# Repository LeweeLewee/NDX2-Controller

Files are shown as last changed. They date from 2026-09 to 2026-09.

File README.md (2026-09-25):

# NDX2-Controller

**25 September 2026: iPhone 11 + selected UGREEN Nexode 20000mAh PD 20W QC Power Bank (D030).** Physical design resumes with [concealed internal phone mounting](docs/hardware/river-stone/iphone-mount/README.md) for agreement. [Waveshare CAD/slicing is parked fallback](docs/hardware/river-stone/fallback-waveshare.md). The earlier visual implementation remains unapproved; no iOS implementation is authorized by this mounting brief. Read the [current continuation](docs/continuation-prompt.md).

A compact, battery-powered coffee-table touchscreen for native Naim music playback, starting with TIDAL.

Project repository: [leweelewee/NDX2-Controller](https://github.com/leweelewee/NDX2-Controller).

**Status: M2 hardware-independent software implemented and tested on the development host; hardware validation remains open.** See the [M2 runbook](docs/m2-software.md), [v1 contract](docs/controller-contract-v1.md) and [native firmware foundation](firmware/README.md). Native TIDAL collection browsing, album/playlist playback, queue edits, transport control and 24-bit playback have been demonstrated on an NDX 2 using a computer. Public TIDAL catalogue search and pagination also pass live tests. Search-result handoff to native Naim playback has passed through the UI; wired System Automation volume down/up are now audibly confirmed and available in the UI. The ESP32 fixture firmware and shared desktop LVGL UI now compile; the physical controller remains unbuilt and unvalidated.

The project's TIDAL developer app is created. Its metadata-only adapter retrieves ranked artists, tracks, albums and playlists. The prototype also supports voice input and live AI music discovery; microphone transcription is user-confirmed. TIDAL account collection controls and persistent Back navigation are implemented; see the collection documentation for live evidence and remaining feature coverage.

The frozen reference is tagged `software-feasibility-v1`. Start the next phase from the [milestone closeout and detailed-design handover](docs/milestone-handover.md).

**Published checkpoint and continuation, 22 September 2026:** [M2 closeout](docs/m2-closeout.md) and [continuation prompt](docs/continuation-prompt.md). The [desktop UI is approved](docs/ui-review/approval.md); the [shared LVGL port and fixture evidence](docs/m2-ui-parity.md) now cover the approved core screens and interactions. Approval does not imply native UI parity or physical acceptance.

## The product

- Compact form with flexible proportions, bespoke touch interface and a substantial, well-finished 3D-printed enclosure.
- Selected hardware: iPhone 11 and UGREEN Nexode 20000mAh PD 20W QC Power Bank (D030). Concealed mounting and exact bank variant/fit are being resolved; physical validation is outstanding.
- Large rechargeable battery and deliberate weight; cable-free use on the coffee table.
- Weeks of standby is a target, not a measured specification.
- Full TIDAL browsing and native playback; other sources can follow.

**The NDX 2 must use its native Naim TIDAL playback path.** The controller and any supporting Pi handle commands and metadata, never audio relay or transcoding. Alternative playback protocols do not satisfy this requirement.

## Documentation

Start current work with the [detailed-design plan](docs/detailed-design-plan.md), [display selection history](docs/hardware/display-comparison.md), [deployment design](docs/deployment-design.md) and [physical interaction trials](docs/interaction-design.md).

| Document | Purpose |
| --- | --- |
| [Updated design concept](docs/design-concept.md) | Historical Waveshare concept; current hardware is D030 |
| [Voice and AI discovery](docs/voice-discovery.md) | Describe a mood, refine suggestions and explore native TIDAL content |
| [TIDAL collection](docs/tidal-library.md) | Real hearts, library saves, account connection and Back navigation |
| [Prototype UI](docs/prototype-ui.md) | Run the 800 × 480 demo and configure the experimental live bridge |
| [Product brief](docs/product-brief.md) | Requirements, constraints and unresolved choices |
| [River Stone enclosure](docs/hardware/river-stone/README.md) | Stationary original 01 concept, dimensioned packaging and build constraints |
| [Hardware and parts BOM](docs/hardware/README.md) | Design baseline, parts, sourcing and validation |
| [Architecture](docs/architecture.md) | Control path, responsibilities and integration boundaries |
| [Evidence](docs/evidence.md) | What the live tests actually established |
| [Decisions](docs/decisions.md) | Agreed decisions and their rationale |
| [Roadmap](docs/roadmap.md) | Work and acceptance criteria for the next prototype |
| [Portable desktop package](docs/m2-package.md) | Bundled runtime, launcher and external-state upgrades |
| [Host controller setup](docs/m2-setup.md) | Private pairing, status, read-only verification and local recovery |
| [Development](docs/development.md) | Running diagnostics, tests and keeping records |
| [Research record](docs/research/native-tidal-feasibility.md) | Detailed research and references |

## Tools

Python 3.9+; no third-party dependencies. From the repository root:

```sh
python -m unittest discover -s tests -v
python tools/naim_native_probe.py NDX_IP --output local/naim-inventory.json
```

Replace `NDX_IP` with the streamer's private IPv4 address. The probe is read-only and saves a filtered interface inventory. It does not prove native playback by itself. See [development notes](docs/development.md) before using it.

Live reports and device-specific configuration belong in ignored `local/`. No credentials or raw network captures belong in Git. `tools/naim_client.py` is an experimental native control client; `tools/check_transition.py` is an explicit live playback test. Neither is production firmware. See the development notes for authorized live use.

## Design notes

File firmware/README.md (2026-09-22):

# Native embedded UI foundation and HP-01 build

Target: Waveshare ESP32-S3-Touch-LCD-4.3B, standard without case, SKU 27848, landscape 800 × 480. This is C/LVGL firmware, not a browser. Shared controller, protocol and UI code serve both ESP32 and SDL. Hardware operations are explicit callbacks; unsupported battery/sleep/capture report unknown or unavailable. Default startup and all verification use silent fixtures.

## Reviewed official example and pins

Reviewed 21 September 2026: [Waveshare 4.3B ESP-IDF guide](https://docs.waveshare.com/ESP32-S3-Touch-LCD-4.3B/ESP-IDF) and the [linked official archive](https://files.waveshare.com/wiki/ESP32-S3-Touch-LCD-4.3B/ESP32-S3-Touch-LCD-4.3B-BOX-Demo.zip). The guide describes SDK 5.5.2 and a differently named example; the archive contains `ESP-IDF/08_lvgl_Porting` with SDK **5.2.0** in `sdkconfig.defaults`. The inspected archive compiles with official ESP-IDF tag **v5.2**, commit `11eaf41b37267ad7709c0899c284e3683d2f0b5e`, and its GCC 13.2.0 toolchain. This establishes compilation compatibility, not board compatibility.

Archive SHA-256: `57186c266f5ed5d9cd22b80b3d3d1d19d54dec2449d7ec220c8b3abc60ee0092`.

Archive component pins: LVGL **8.4.0** (`4495f428630cc1741bd8bfd977f080e8460e8e8d`); esp_lcd_touch **1.1.2** (`54e9ba5f17d0f007f5a4073240b5f6c20e099f91`); GT911 **1.1.1~1** (`30d2504a679c1cb0d10833f772d97453098b4c08`). These component directories are already in the archive. The preparation script removes floating main component requirements and retains those vendored sources and licenses. No vendor code is committed to this repository.

Review findings: 800 × 480 selected; 16-bit RGB; PSRAM and 16 MB flash defaults; I2C 8/9 in the driver; touch disabled in the delivered header; touch reset/IRQ both `-1`; backlight delegated to vendor board code. Driver files stay in the generated project, separate from `shared/`. No GPIO4 wake assumption is implemented. The archive's BOX name is not evidence that every board revision is identical. Verify against the physical standard board before enabling touch or flashing.

## Reproducible preparation and build

From repository root in PowerShell:

```powershell
New-Item -ItemType Directory -Force local/m2
Invoke-WebRequest 'https://files.waveshare.com/wiki/ESP32-S3-Touch-LCD-4.3B/ESP32-S3-Touch-LCD-4.3B-BOX-Demo.zip' -OutFile local/m2/vendor.zip
python tools/prepare_m2_firmware.py --out local/m2/esp32-compile-v2
```

The script refuses an existing output directory or changed archive hash. For another build choose a new directory; it never overwrites a checkout. It overlays the shared C UI and ESP entry point, disables stock auto music/demo UI, and inserts wake-contact filtering before LVGL input. Touch remains off until revision review. After that review, prepare a **new** output directory with `--touch-reviewed`. This flag does not configure any wake GPIO or sleep mode.

Install official ESP-IDF **v5.2** and matching tools outside the repository. On this Windows host the SDK lives at `$env:USERPROFILE/.espressif/esp-idf-v5.2`, with its isolated Python 3.11 environment at `.espressif/python_env/idf5.2_py3.11_env`. Installation for a new host (use a base Python 3.11 interpreter, not an activated virtual environment):

```powershell
git clone --branch v5.2 --depth 1 --recurse-submodules --shallow-submodules https://github.com/espressif/esp-idf.git "$env:USERPROFILE/.espressif/esp-idf-v5.2"
py -3.11 "$env:USERPROFILE/.espressif/esp-idf-v5.2/tools/idf_tools.py" install --targets esp32s3
py -3.11 "$env:USERPROFILE/.espressif/esp-idf-v5.2/tools/idf_tools.py" install-python-env
python tools/build_m2.py esp32
```

The runner refreshes only owned overlay sources in the generated directory, validates its archive marker, and disables unused vendor demos. Build output uses `$env:USERPROFILE/.espressif/ndx2-m2-build` to avoid Windows dependency-file path limits; source remains in this checkout. The fixture binary compiled successfully (approximately 516 KiB, fitting its 1 MiB application partition). No flash or efuse operation ran. Save configuration/build manifests privately. HP-01 remains open; flashing requires the actual board and revision review.

## Shared SDL desktop build

The verified Windows runner pins CMake 3.28.3, Ninja 1.11.1.1, Zig 0.13.0 and SDL 2.30.12. From repository root, after preparation and SDK installation:

The downloaded SDL development archive SHA-256 is `dddafbf0705a8cbe1f97c69680886ce147ed4d38f1d04e03523681298e081b0f`. Verify a fresh download before extraction. These instructions reproduce the dependency versions and build process; generated binary timestamps and local paths can affect binary hashes.

```powershell
python -m pip install --target local/m2/build-tools cmake==3.28.3 ninja==1.11.1.1 ziglang==0.13.0
Invoke-WebRequest 'https://github.com/libsdl-org/SDL/releases/download/release-2.30.12/SDL2-devel-2.30.12-mingw.tar.gz' -OutFile local/m2/SDL2-devel.tar.gz
tar -xzf local/m2/SDL2-devel.tar.gz -C local/m2
python tools/build_m2.py desktop
python tools/m2_native_demo.py
```

Both native CTests pass. Run `local/m2/desktop-verified/ndx_fixture.exe` for the standalone fixture. `m2_native_demo.py` uses that compiled UI, SDL pointer events, synthetic pairing and real localhost TLS; it asserts one silent native-play request and refreshed state, then records thirteen framebuffer BMPs in ignored `local/m2/native-captures`. The SDL transport worker launches `m2_pipe.py`; credentials remain in the protected Python vault and never cross the pipe. A public config supplies `url`, `trust` and `state` paths; live connections require an explicit `allow_live` setting. Tests never enable it. This Windows transport is not a portable desktop release. See [M2 runbook](../docs/m2-software.md).

## Diagnostic and physical boundaries

ESP32 emits `HP01` timestamped fixture event names plus free/minimum heap. Hooks include boot, native-resolution simulation, bounded amplifier simulation, capture cancel, backlight-unbound and sleep-blocked. Add revision-specific timing/PSRAM/power markers as the board port becomes available; no token, address or user query is logged. Record serial/debug overhead and repeat power measurements detached. Physical HP-01 still needs backlight-off and verified light/deep-sleep implementations; unsupported callbacks deliberately fail rather than pretending to measure sleep.

`esp32/bridge_transport.c` implements the same v1 codec using `esp_http_client` on a FreeRTOS worker, with provisioned CA trust, hostname verification, redirect rejection, bounded 32 KiB responses, deadlines and no mutation retry. Replies from obsolete connection generations are discarded. Startup requires encrypted NVS plus runtime secure boot and flash encryption; default builds fail closed to the labelled fixture. Protected NVS namespace `controller` expects `url` (ending `/v1/request`), `credential`, `trust` (PEM), `ntp`, `ssid` and `password`. This is a provisioning interface, not a completed production provisioning tool. Do not enable irreversible security settings or provision real credentials from this recipe. The SDK compiles the worker, but default fixture builds may link out its gated network path. On-device Wi-Fi/TLS, certificate-time bootstrap, revocation, protected provisioning and power-loss behaviour remain untested. Provider credentials remain on the bridge. See [hardware-arrival checklist](../docs/m2-software.md#hardware-arrival-checklist).

## Approved native UI port — 22 September 2026

The shared renderer now implements the D020 core layout and interaction slices; see [parity/evidence](../docs/m2-ui-parity.md). Native smoke includes immediate-record voice entry, restart, explicit search, cancel, an accelerated 30-second stop without submission, independent artist-follow/track-save and consumed wake contact. `06-voice-search.bmp` supersedes the historical review-step capture; thirteen captures now document the flow. Font sizes 16/20/24/32 are explicitly enabled by the owned build overlay, retaining LVGL 8.4.0 and ESP-IDF v5.2. No new SDK/dependency download or board operation is needed.

## Authenticated artwork preview - 22 September 2026

Shared LVGL/codec accept fixed 80 x 80 RGB565 artwork previews over the authenticated bridge. No firmware image-decoder dependency or SDK pin changed. Three CTests cover controller state, strict protocol bounds and native UI cancellation/artwork failures. Desktop TLS smoke checks artwork pixels before/after a silent track change. Latest ESP32 build: `0x92c00`, 43% free; compiler evidence only. Standalone firmware fixtures have no artwork pixels yet.

The host bridge uses already-installed Pillow 12.2.0 for bounded JPEG normalization and local fixtures. Host dependencies are pinned in `tools/requirements-m2.txt` (also cryptography 46.0.7 for certificates). On a fresh host install that file with the chosen Python environment; no download was needed for this checkpoint. See [bounds and evidence](../docs/m2-artwork.md).

## Persistent local preferences - 22 September 2026

Palette/brightness intent/timeout use the shared bounded preference record and local platform storage callbacks. Windows uses SDL's per-user `NDX2/Controller` directory, or `--preferences PATH` with an existing parent. The ESP32 NVS adapter uses `display_prefs/record`, never erases on storage error and does not change credential protection gates. No hardware brightness/sleep effect is implemented.

Run `python tools/m2_preferences_demo.py` after the desktop build for isolated two-process restart evidence and native captures. All smoke tools supply temporary preference paths, preserving normal user preferences. Four CTests now include atomic storage/recovery and native save behavior. ESP32 storage remains compiled-only; physical latency/power-loss/endurance are open. See [preferences runbook](../docs/m2-preferences.md).

## Offline recovery checkpoint

After the desktop build, run `python tools/m2_recovery_demo.py` to exercise the real worker/helper over paired TLS with startup outage, delayed replies and a new bridge boot ID. All commands target silent fixtures. Four CTests include expanded LVGL recovery assertions; the separate transport executable is driven by this Python fixture rather than standalone CTest. Shared UI uses an eight-second pending deadline, generation invalidation and conservative unknown outcomes. ESP32 compiles (`0x971f0`, 41% free); no physical networking or recovery is claimed. See [recovery evidence](../docs/m2-recovery.md).

## Host enrollment foundation

New desktop controller records can be created with the tested host enrollment library and are bound to their supplied HTTPS origin/trust file. The helper validates these bindings; legacy fixture records remain compatible. `python tools/m2_provisioning_demo.py` exercises enrollment/revocation/replacement using temporary synthetic state and verified loopback TLS. This does not create ESP32 NVS images, expose secrets or enable the gated hardware transport. See [design, recovery and evidence](../docs/m2-provisioning.md).

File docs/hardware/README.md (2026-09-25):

# Hardware

> **D030 update — 25 September 2026:** active hardware is iPhone 11 + selected UGREEN Nexode 20000mAh PD 20W QC Power Bank. See [current mounting and power packaging](river-stone/iphone-mount/README.md). Waveshare-specific parts, experiments and purchase recommendations below are fallback history; actual prior order records remain valid. This update does not cancel orders or authorize more purchases.

Status: concept and parts planning; no physical build or purchases recorded.
Last reviewed: 21 September 2026.

**Selected, 21 September 2026 (D017): Waveshare ESP32-S3-Touch-LCD-4.3B, standard without case (SKU 27848), 800 × 480.** Android is ruled out. Hardware validation remains outstanding; no purchase is recorded.

Start with the [Waveshare HP-01 protocol](first-experiment.md) and [next-phase plan](../detailed-design-plan.md). The [Android comparison](display-comparison.md) is retained as superseded history, not active work.

Current enclosure: **original 01 River Stone, stationary on the table**. See [dimensioned packaging and construction study](river-stone/README.md).

Repurposed phones are excluded from the current design for visual reasons; a dismantled-phone approach is not being pursued. Use a dedicated display assembly; see [decision D015](../decisions.md#d015--dedicated-display-repurposed-phone-route-ruled-out).

## Design baseline

- Compact coffee-table controller with a bespoke touch UI and a substantial, serviceable 3D-printed enclosure.
- Rectangular or square proportions are acceptable: screen quality and interaction take priority over aspect ratio.
- A separate large rechargeable battery lives low in the base. An included small battery adds no selection value.
- Weeks of standby is a target, not a measured specification. Screen-off standby is the working LCD direction; keeping now-playing continuously visible has a different energy budget.
- Touch wake remains a requirement to validate. Powering down the entire display board also disables its touch electronics unless a wake circuit remains powered.
- Native Naim TIDAL playback stays on the NDX 2. Controller and optional existing Pi carry commands and metadata only.

## Documents

| Document | Purpose |
| --- | --- |
| [Hardware design](design.md) | Electrical boundaries, physical layout and screen record |
| [Parts BOM](bom.md) | Authoritative part IDs, quantities, status, sourcing and costs |
| [Research and selection](research.md) | Open decisions, candidate routes and next actions |
| [Power component review](power-review.md) | Source findings, shortlist and compatibility gates |
| [Power budget and validation](validation.md) | Runtime assumptions and hardware acceptance checks |

## BOM management

Use one stable HW identifier per functional item. The BOM is the source of truth; do not maintain a second independently edited spreadsheet.

Selection states: **existing**, **selected**, **preferred**, **candidate**, **research**, **design**, **optional**, **excluded**.
Track procurement separately: **not ordered**, **ordered**, **received**, **assembled**, or **existing / inventory unverified**. A preferred part is not a purchase instruction.

Before ordering, record exact manufacturer part number, board revision, supplier link, quantity, connector/polarity requirements, dated unit price and currency. Record shipping and taxes separately. Unknown cost is **TBD**, never zero. Included functions are not additional purchased parts. Alternatives are mutually exclusive, not additive.

After receiving a part, record actual revision and dimensions, paid cost, sanitized order reference and validation evidence. Keep private receipts/account details in ignored local/. Record substitutions and accepted choices in [decisions](../decisions.md), hardware results in [evidence](../evidence.md), and milestone changes in [roadmap](../roadmap.md).

Complete the software control-loop milestone before final component purchase and final enclosure CAD. Research and provisional layout work can proceed now.

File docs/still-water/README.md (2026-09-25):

# Still Water: visual design package for the native UI

> **Current selection — 25 September 2026 (D030):** user selected iPhone 11 and UGREEN Nexode 20000mAh PD 20W QC Power Bank. Waveshare is parked fallback. Earlier “selection open” text below is historical. [Concealed mounting proposal](../hardware/river-stone/iphone-mount/README.md) governs the current physical discussion; the 118 × 54 mm window remains provisional. The draft custom battery/boost/MCU architecture, operating configuration and runtime expectations below are not validated or adopted wholesale. Do not execute embedded implementation prompts from this hardware-selection update.

23 September 2026. Design handover for the Still Water UI, platform-neutral pending screen selection between the iPhone 11 (`iphone-architecture.md`) and the Waveshare 4.3B (`spec.md` Appendix A). Bridge protocol semantics, recovery, security and D011 are out of scope and must not change.

| File | Purpose |
|---|---|
| `iphone-architecture.md` | Roles, phone configuration, display window, app modules, power module, budget and the measurement gates |
| `spec.md` | The design: principles, tokens, rest-state machine, every screen in design units with coordinates, artwork colour extraction, fonts, motion, abnormal states, acceptance criteria |
| `decision-draft.md` | D028 wording for the decision log |
| `codex-prompt.md` | Two briefs: bridge additions now (platform-independent), and the iOS app once the screen is selected |
| `evaluation.md` | The design evaluated against the project goals and the automated gate, with what was changed as a result |
| `reference/still-water.html` | Interactive prototype, 22 states (open in a browser; fictional music, no device commands) |
| `reference/*.png` | Reference renders of all 22 states at exactly 800 × 480 design units, at the spec type sizes |
| `tools/still-water-gates.py` | Playwright script that renders every state and checks targets, overlaps, text size, contrast and clipping |

## This sprint

Lock the design, not the platform: extend the prototype to the full state matrix, freeze this spec at v1.0, put the prototype on the iPhone 11 on the table under Guided Access, run the two-day standby measurement, and have Codex do only the bridge additions. Choose the screen at the end of the sprint; then one final build.

## Scope

In: visual composition, typography, colour, hierarchy, motion, touch layout, rest ladder timing based on last touch and transport state.

Out: presence sensing, light seam, enclosure CAD changes beyond the inlay window, queue editing, AI suggestions beyond the existing search path, any new network route from the phone, always-on operation, any battery claim.

## Panel check

Section 0 of `spec.md` records the iPhone 11 panel facts and section 0b the window and unit mapping; Appendix A records the Waveshare panel facts and LVGL implementation notes.

## Precedence

D027 authorises this redesign of the visual layer and D028 (draft) the platform. Where this package conflicts with `docs/m2-object-design.md` pixel geometry or `docs/hardware/design.md` display selection, this package wins. Where it conflicts with `docs/decisions.md`, `docs/controller-contract-v1.md` or `docs/m2-recovery.md`, those win and the conflict should be recorded in the roadmap rather than resolved silently.

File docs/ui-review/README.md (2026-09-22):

# Approved UI design

The user approved the desktop design on **22 September 2026**, after the icon-only Search refinement. [Approval and baseline identity](approval.md) governs the design; [index.html](index.html) is its interactive visual reference. [Historical notes](review-history.md) preserve earlier proposals without making them current requirements.

## Review locally

From the repository root:

```powershell
python tools/ui_design_review.py
```

Open http://127.0.0.1:8766/. This loopback-only server exposes the board and an optional existing fixture capture, with no player, bridge API, credentials or microphone access. Missing `local/m2/native-captures/01-now.bmp` affects only the comparison image. Browser-local notes/preferences are not repository acceptance evidence.

## Current baseline

- 800 × 480; 240 px artwork left, metadata and all controls right. Four sections: Playing, Find, Collection, Queue. Voice is inside Find.
- Five evenly spaced, unboxed controls: previous, play/pause, next, speaker-minus, speaker-plus. Quiet Back; no redundant section titles, Volume label, play circle or volume capsule.
- Bitrate beside source, separate timeline; track heart and title/artist/album links. Real metadata must be authoritative or explicitly unavailable.
- Artist follow/unfollow and status; album/track + Library or checked Library; saved, unsaved and unknown remain distinct.
- Magnifying-glass search and microphone icons. Microphone opens recording immediately; Stop & search, Restart, Cancel. Thirty-second bound, no automatic submission or playback.
- Settings via gear: Display, Connection, Device; Sage/Sand/Slate, brightness and timeout preferences, Wi-Fi/pairing/setup and diagnostics direction.

Settings, membership, bitrate and recording are labelled simulations. Brightness is a browser visual approximation; timeout is stored without implementing sleep. Alternative artwork/navigation options are comparison aids, not additional required modes.

## Implementation boundary

The browser board is approved design, **not ESP32 runtime or proof of shared LVGL parity**. Port it to the existing shared C/LVGL UI, retain authenticated bridge semantics, and validate desktop flows before hardware. Loading/error/transcription-failure details may need further design review. Touch sizes, wake release, readability, battery and microphone still require physical evidence. HP-01 and physical P3/P4/P5 remain open.

Continue with [the implementation handover](../continuation-prompt.md). No queue/playlist editing or automatic AI playback is included.

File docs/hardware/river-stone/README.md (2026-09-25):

# Original 01 River Stone: stationary enclosure

> **Visual reference confirmed: original 01 River Stone only**, for both body and screen interface. Concealed iPhone mounting must preserve microphone acoustic paths.

> **25 September 2026: active hardware is iPhone 11 + selected UGREEN Nexode 20000mAh PD 20W QC Power Bank.** Start with the [concealed mounting layout, section and paper aperture trial](iphone-mount/README.md). Everything below describing the Waveshare packaging, CAD and slicing is [parked fallback history](fallback-waveshare.md); its dimensions and print next steps do not govern the iPhone build.

Status: dimensioned packaging study, 20 September 2026. Original visual concept selected by the user; stays on the coffee table. Dimensions and construction details below are engineering proposals, not user-approved measurements or manufacturing release.

**Latest manufacturing check:** [P1S slicing study and small fit-trial 3MF](slice-v1/README.md). Provisional Generic PLA; physical testing pending.

**Latest CAD revision:** [v3 reinforced shell, matching cover and screen-edge bevel](shell-v3/README.md). Full-shell print release remains pending.

**Shell baseline, 21 September 2026:** see the [shell and assembly study](shell-v1/README.md) for actual solids, revised component positions and insertion clearance. The plan-view study below is retained as its starting point.

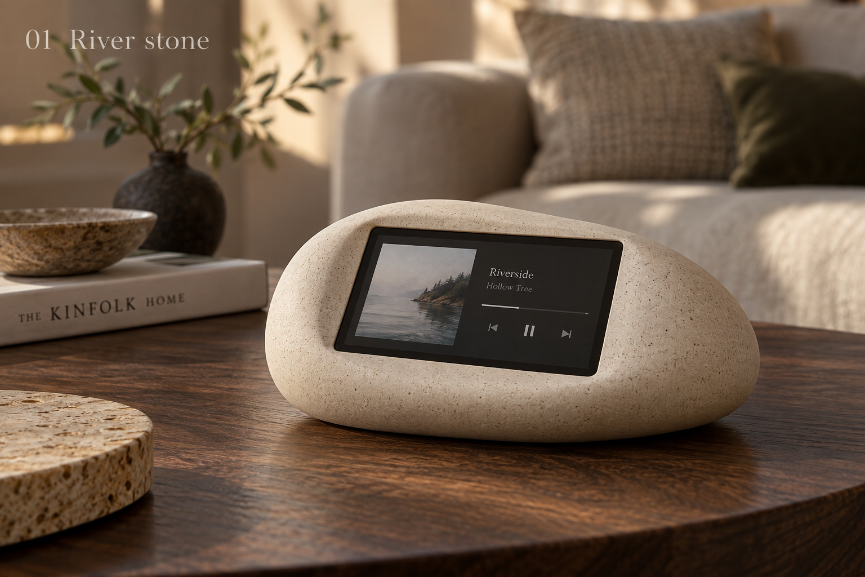
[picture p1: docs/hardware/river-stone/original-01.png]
Selected original River Stone


Preserve the original's low asymmetric pebble, soft shoulders, inset landscape screen and mineral surface. The four later variations and Crescent embrace are superseded. Do not evolve this into an exposed monitor stand or stacked removable controller.

## Architecture and simplicity

One stationary controller, one battery, one main shell and one recessed underside cover. No separate handheld battery, angle rails, docking magnets, transmitter/receiver or controller-to-base charge transfer. Rear cable charging is the working proposal; ordinary operation remains cable-free. This does not select a charger or wiring scheme. Existing external charger/power-path research remains applicable.

The P1S and 0.4 mm nozzle are the user's home manufacturing constraint. Prefer a filament surface that is acceptable directly from the printer. Fine stone-effect speckling is a visual direction, not a selected filament. Material compatibility, nozzle requirements and sample finish must be checked for the exact product; no assumption that all mineral-filled filaments suit the stock nozzle. Acetone smoothing and painting are not requirements.

## Dimensioned layout

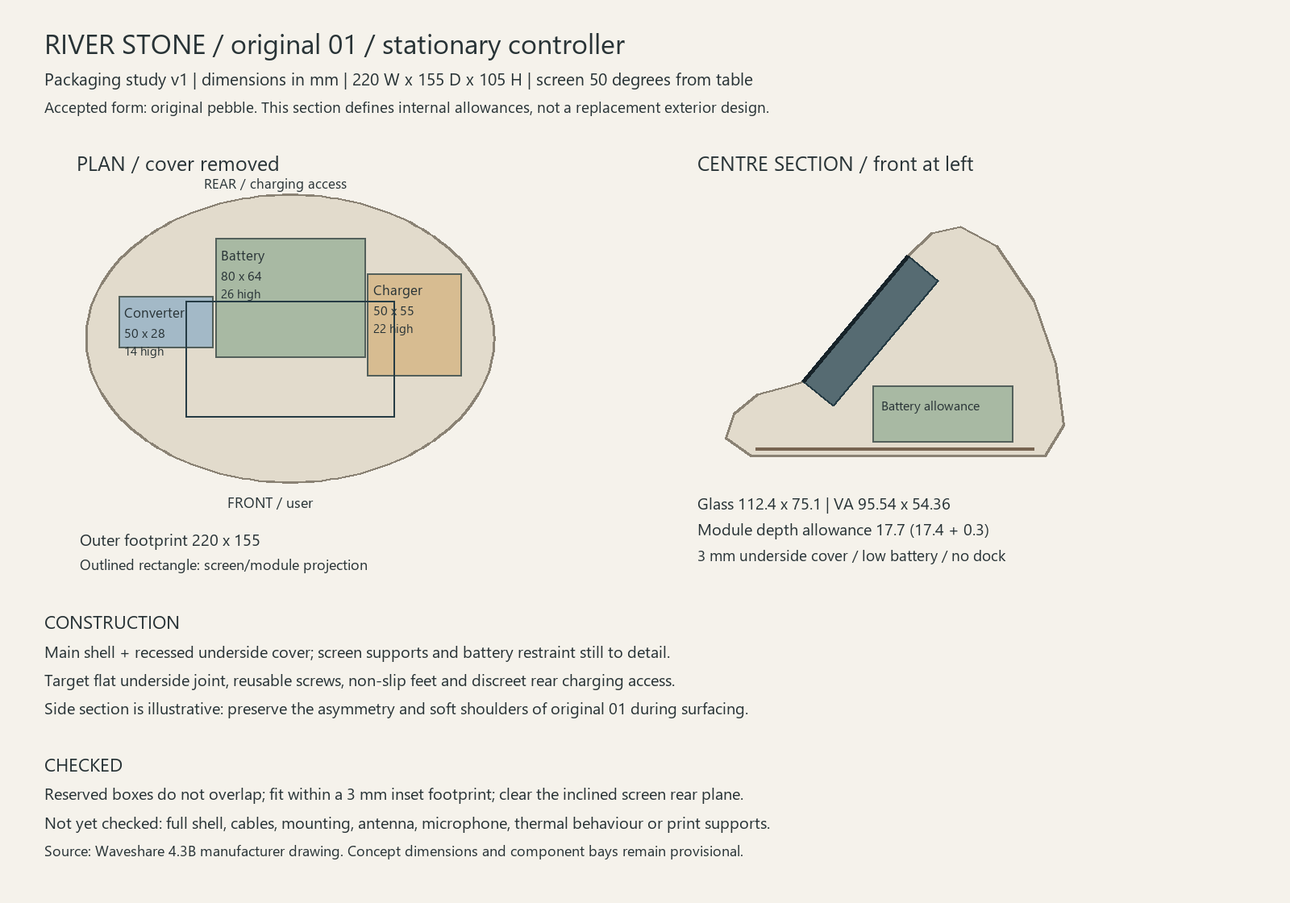
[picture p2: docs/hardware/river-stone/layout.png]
Packaging plan and side section


[Vector drawing](layout.svg) · [Numerical checks](clearance-checks.json) · [Generator](../../../tools/river_stone_layout.py)

| Item | Working allowance |
|---|---|
| Overall body | 220 W x 155 D x 105 H mm; bounding envelope, not an optimized minimum |
| Screen | 50 degrees from table, lower lens edge 34 mm above underside datum |
| Lens | 112.4 x 75.1 mm; supplier tolerance +/-0.1 mm each |
| Visible area | 95.54 x 54.36 mm; supplier tolerance +/-0.15 mm each |
| Screen module depth | 17.7 mm allowance includes drawing's 17.4 +/-0.3 mm; excludes plugged cables |
| Battery space | 80 x 64 x 26 mm, starting 6 mm above underside |
| Charger space | 50 x 55 x 22 mm, rotated planning allowance |
| Converter space | 50 x 28 x 14 mm |
| Shell / cover | Start with 3 mm nominal; final shell offset, ribs, joints and inserts unresolved |

Coordinates in the generator: X left/right, Y positive rear, Z positive up; underside datum Z=0. Bay sizes are installation reservations, not supplier dimensions. Battery reference is the earlier 69 x 54 x 18 mm protected pack candidate; it is not purchased or electrically approved. A rectangular reservation must not be mistaken for an actual serviceable cavity.

The screen's 800 x 480 pixel canvas is not its physical aspect ratio. Use the manufacturer's VA dimensions for physical visualizations. Source: [Waveshare drawing archive](https://files.waveshare.com/wiki/ESP32-S3-Touch-LCD-4.3B/ESP32-S3-Touch-LCD-4in3B_Drawing.zip). The drawing was downloaded and visually inspected; the local original source is retained with the design-session artifacts. No mounting-hole or cable-clearance release is inferred from these measurements.

## What the checks establish

The three rectangular reservations are mutually disjoint, fit inside an ellipse with each semi-axis reduced by 3 mm, and lie below the infinite rear plane of the inclined screen module. This ellipse is a footprint approximation, **not a true constant-thickness offset of a final shell**. Normal gaps to the screen rear plane are battery 8.10 mm, charger 3.01 mm and converter 19.64 mm. The charger gap is the tightest: mounts, cable routes and tolerances may require moving it or increasing the envelope.

The side section is an illustrative centre profile. It is not the exterior CAD surface; the original image governs the asymmetric shoulders. Full shell clearance, fasteners, cable plugs/bends, antenna clearance, microphone hardware, touch force stability and heat are unverified. Do not print this drawing as a fabrication template or buy components based on it.

## Assembly proposal

1. Print the main shell and removable underside separately. Start evaluating the shell with its underside opening toward the bed; flatten the hidden joint rather than supporting a rounded underside. Screen aperture edges and upper internal surfaces still need a slicer overhang check. A no-support claim is premature.
2. Insert the screen from below through the open underside. Use discrete internal mounting supports and a compliant perimeter gasket; no concentrated fastener load on the glass. Retainer geometry and insertion sweep follow actual board mounting details.
3. Fit an insulated removable battery restraint and the two power boards to the underside assembly. Allow a service loop so the cover can open without pulling connectors. Do not compress the pack. Keep antenna clearance and optional microphone placement out of the battery/ballast region.
4. Close using reusable screws into designed bosses/inserts. An initial four-screw concept is reasonable, but coordinates and lengths must follow the interior layout. Put non-slip feet where they do not conceal required service screws.
5. Provide a discreet rear inlet and strain relief appropriate to the eventual power path. Preserve programming access. A slot or port cut-out is not released until the chosen connector, plug and cable bend are modelled.

## Next engineering work, without another concept-selection gate

- Build the asymmetric shell surface to the original reference, using these reservations as keep-outs. Assess whether the 105 mm high rear can be lowered while retaining the screen angle and access.
- Incorporate the manufacturer's STEP and measured connector/mount information; perform a real shell offset and insertion-path check before a fit STL.
- Resolve charger placement with its actual board outline and wiring; maintain the existing power research limits. Battery current and runtime require bench evidence.
- Reserve microphone hardware consistent with the accepted voice feature; do not silently omit it or claim its volume is already proven.
- Slice a partial bezel/mount sample before committing to the full decorative shell, then test viewing and touch on the actual table.

The only later user input likely to matter is actual seated usability or a choice between credible finish samples. This study does not require another aesthetic confirmation.

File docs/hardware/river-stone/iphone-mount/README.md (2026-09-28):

# iPhone 11 / stone mounting proposal

25 September 2026. **Active hardware: iPhone 11 and the user-selected UGREEN Nexode 20000mAh PD 20W QC Power Bank (D030).** The Waveshare enclosure and slices are [parked fallback work](../fallback-waveshare.md). This document proposes the mechanical interface for agreement; it records the accepted paper aperture but does not release fit CAD or authorize an app implementation.

## Reference and intended appearance

Sole visual reference: original 01 River Stone

**User clarification, 25 September 2026: original 01 River Stone is the sole visual reference for both the body and screen-to-stone interface.** Preserve its low asymmetric pebble, soft shoulders, inset landscape screen and mineral finish while adapting the internals for iPhone 11 and the selected UGREEN bank. The supplied “04 Tide pool” image is retained only as superseded reference history; do not use its bowl/rim geometry to drive the design. The section diagram below explains mounting layers only and does not prescribe the exterior contour.

## Mounting layout — revised 27 September 2026

Front, section, underside and acoustic reservations

[Layout checks](layout-checks.json) · [1:1 paper aperture template](mask-trial.svg) · [Reproducible layout generator](../../../../tools/iphone_mount_layout.py)

The user repeated the selected bank name, UGREEN Nexode 20000mAh PD 20W QC Power Bank, and authorized proceeding. Use the matching manufacturer's 147 × 72 × 28 mm envelope to progress the layout; the exact physical unit and port arrangement still require checking before a fitted cradle. This is a working assumption, not a substitution of another power bank or a request to reopen the selection.

| Proposal | Working value |
|---|---|
| Overall planning bounds | 240 W × 170 D × 105 H mm |
| Phone angle | 50 degrees from the table |
| Lower phone glass edge | 36 mm above underside datum |
| Visible aperture | 138.9 × 63.7 mm bounds; size passed by user; 6 mm inset from every outer phone edge |
| Aperture corner radius | R3 mm all four corners; user passed the rounded aperture trial |
| Local glass recess | 1.2 mm trial target |
| Bank bay | 151 × 76 × 32 mm, around the 147 × 72 × 28 envelope |
| Rear-of-phone reserve | 6 mm beyond nominal phone body, not a measured camera dimension |
| Phone connector / bank service reservations | 25 mm each at opposite sides; actual plugs and bend radius unmeasured |

The bank sits across the base, low and behind the inclined phone. Coordinates and exact reservations are in the JSON. The bank bay clears the conservative infinite phone-rear allowance plane by **15.08 mm vertically** at its closest corner. This is only an analytical plane/box check. It does not establish curved-shell clearance, fitting tolerances, vent dimensions, screw access, insertion or temperature. Body dimensions and tilt are engineering proposals; they are not dimensions recovered from the original concept image. Revisit them after the mask and hardware measurements.

Use a cradle with open front-notch, rear-camera and connector-end zones. Avoid a full clamshell around the phone. Keep long-edge buttons free; place padded chassis supports only after mapping the actual button and microphone positions. Interrupt the light-seal gasket around the front acoustic inlet and preserve an open route beneath an optically concealing lip. Reserve a separate rear-camera acoustic route and keep the Lightning-end openings clear of cable plugs and restraints. Vents must open to room air above the table contact plane, not into a sealed bank cavity. The sketch shows protected zones, not verified inlet coordinates or finished ducts. Exact port mapping and mounted recordings are mandatory before claiming unobstructed microphone performance.

Assembly proposal: phone into cradle, cradle into open stone, connect lead, then fit the separately restrained bank and underside cover. The projected volumes overlap, so assume the bank must come out first for phone removal; independent phone removal with the bank installed is not proven. No load-bearing back clamp over the phone battery, and no lens contact.

Print the paper template at 100% and verify its 50 mm scale. Cut the window and hold the mask over the phone without sticking it across the earpiece or any microphone opening. Check notch/edge concealment, oblique views and touch reach; remove the paper for unmounted voice baselines. The next 3D sample should reproduce the aperture edge and interrupted gasket/acoustic passage, not just a decorative frame. Compare Voice Memos and front/rear camera recordings, then the intended voice app, at the same distance/orientation before and after mounting. Apple provides separate microphone checks for [voice recordings and both camera directions](https://support.apple.com/en-gb/101600). This is a test plan; nothing has been physically recorded or printed here.

## Recommended construction

Interface schematic

Mount the intact, case-free phone from inside/underneath the stone in a removable cradle. Keep the phone's battery and housing intact. Locate it on padded chassis/perimeter supports with clearance for buttons and the rear camera bump; do not load the camera lenses, active display or battery area. Rear keeper screws close against cradle hard stops, rather than squeezing the phone tighter as they turn. The cradle attaches to internal bosses and can be removed after opening the underside cover.

An opaque stone lip conceals the phone perimeter; notch and corner concealment must be checked with the enlarged opening. A thin, replaceable black closed-cell gasket under that lip controls light leaks and the visible joint; it is not the structural clamp. Keep pad contact on verified non-display perimeter regions. The exposed touch surface is the phone's own glass: no added glass/acrylic overlay, external phone frame or adhesive bonding to the phone. A separate hidden mask insert remains available if printing the stone lip cleanly proves difficult; it is not an extra required visible trim.

Use a shallow local glass recess, initially around 1–1.5 mm for a physical mock-up, with a gently relieved stone edge. That is a proposal, not a print tolerance. The surrounding pebble surface follows original 01 River Stone; the immediate aperture edge must allow a fingertip to reach controls. Avoid a deep vertical tunnel. Keep interface controls away from the lip and verify at seated viewing angles; app layout must match the physical aperture rather than squeezing the entire iPhone interface into view.

## Window and phone envelope

Apple specifies the iPhone 11 body as **150.9 × 75.7 × 8.3 mm**, 194 g, with a 1792 × 828 LCD. These are nominal product dimensions, not a mounting drawing: measure the actual phone, camera projection, buttons and cable plug before fit CAD. [Apple specifications](https://support.apple.com/en-gb/111865).

**26 September revision:** the user rejected the 118 × 54 mm opening as too small and subsequently reduced the proposed overlap to **6 mm measured inward from the outer phone edge**. Apply this to all four edges as the next trial baseline: (150.9 − 12) × (75.7 − 12) = **138.9 × 63.7 mm**, centred on the phone body. This is approximately **38.9% more rectangular opening area**, not a claim about active pixel area. The width and height subsequently passed the user’s physical trial; R3 corner geometry also passed on 27 September; any local microphone relief remains to be verified.

Maximise display exposure within this baseline. A uniform overlap does not prove that the notch is hidden or that the front microphone is clear. Check registration on the actual phone; use local lip relief and an interrupted gasket wherever needed to leave the inlet and a short, broad path to room air open. Do not shrink the whole aperture again merely to hide the notch. Exact relief dimensions await microphone mapping; the rounded paper template is a visual registration aid only. The earlier 755 × 346 pt/1048 × 480 design-unit mapping is superseded for this aperture and must be recalculated from actual screen registration before UI work.

Propose notch left and Lightning connector right when viewed from the front. The notch is at a short end in landscape; the home indicator is along the bottom long edge, not the opposite short end. A physically masked display cannot rely on normal edge gestures for everyday controls. Preserve underside service access for unlocking, exiting the app, restarting and reconnecting; hiding sensors may prevent Face ID and alter automatic brightness. These operating choices need a real phone trial, not assumptions from the concept image.

## Selected power bank and service access

Use the selected UGREEN bank intact in a separately retained bay, low in the base, with access to its button/indicator and charging ports. Do not transfer the earlier bare-cell charger/boost board stack into this architecture automatically. Do not stack the phone directly onto the bank; reserve separation and heat escape paths, and measure charging temperature in the closed enclosure.

The user's product name is the selection. SKU 25683 is a possible match, **not a confirmed substitution**. UGREEN's 25683 listing gives 147 × 72 × 28 mm and 435 g ±5 g; use those only as conditional planning data until the exact SKU is confirmed. Plug bodies, strain relief and cable bends are additional. [UGREEN manufacturer listing](https://www.ugreen.com/en-au/products/au-25683). Earlier 80 × 64 × 26 mm battery reservations cannot accommodate that conditional envelope, so the Waveshare base layout is not reusable as an iPhone fit claim.

A concealed USB-to-Lightning lead is the simplest first charging proposal. Reserve room beyond the phone's connector end and route without trapping the cable beneath the phone. Phone and bank should be removable independently. **Firm user constraint: mounting must not obstruct the iPhone microphones.** Map the actual microphone openings before fixing the cradle, gasket or masking lip; preserve their acoustic paths, including around the connector end. Provide concealed acoustic openings where the stone would otherwise enclose them. Revise the masking rather than sacrifice microphone access. Validate voice pickup in the assembled enclosure; no acoustic performance is claimed yet.

Bank automatic shutoff/restart, concurrent charging/output, charge-window switching, low-load behaviour and total runtime remain unproven. The bridge's D029 charge advice is software evidence only: it does not make this commercial power bank remotely switchable. The older draft MCU/load-switch/pack-gauge architecture and runtime estimates are not adopted by selecting this bank.

## Accepted paper aperture — 27 September 2026

The user passed the window size and subsequently passed the R3 corner revision. The accepted aperture baseline is **138.9 × 63.7 mm, 6 mm overlap from each outer phone edge, and R3 mm circular corners on all four corners**. Preserve these dimensions in subsequent mounting CAD. The radius is in the opening plane; it does not specify a bevel or fillet through the lip thickness. This records the user's paper-template fit result, not independent measurement of the iPhone screen radius.

Next develop the small aperture-and-cradle sample around this accepted opening. Recess, edge touch access, retention, exact microphone passages and mounted acoustic performance remain unverified. Preserve open microphone paths and interrupted gasket.

## Agreement and next physical proof

Recommended agreement: **rear-loaded intact phone; serviceable padded cradle; opaque stone lip; hidden black light seal; original phone glass exposed; shallow local recess.** The user suggested rear/inside mounting; the aperture dimensions above are accepted; cradle and recess dimensions remain proposals.

Before detailed CAD: verify the UGREEN variant; register a removable 138.9 × 63.7 mm paper/card mask with 6 mm overlap on each edge over the actual phone; display alignment marks at the intended UI corners; check notch/edge concealment from sofa and oblique angles, touch at the lip, wake/unlock and voice. Then measure the phone/plug/camera/bank and make a small aperture-and-cradle sample. No need to print the old Waveshare coupons to advance this architecture. Keep printer constraints (P1S, 0.4 mm nozzle, minimal finishing) and the luxury living-room appearance as design gates.

## First printable interface sample — 27 September 2026

[Sample v1: STL, STEP, preview and trial instructions](sample-v1/README.md) preserves the passed aperture and adds an open frame plus loose recess gauges. This is a hand-supported fit sample, not a retaining cradle. CAD and mesh checks passed; slicing, printing and acoustic validation remain outstanding.

## Revised fit sample — 28 September 2026

Use [sample v2](sample-v2/README.md) for the next print. It adds four short end-locating tabs with nominal 1 mm end clearance and 36 mm central end openings, preserving the accepted aperture and existing rails/spacers. No clamping or snap fit. CAD body-clearance and exported mesh checks passed; actual microphone, camera, button and insertion checks remain physical work. V1 is preserved.

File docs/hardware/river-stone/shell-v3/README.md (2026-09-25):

# River Stone reinforced-shell study v3

> **PARKED FALLBACK — 25 September 2026 (D030).** This is Waveshare-specific work, preserved without changing its geometry/results. Active design is [iPhone 11 mounting](../iphone-mount/README.md); old printing/next-step instructions below are suspended. See [fallback status](../fallback-waveshare.md).

21 September 2026. Dedicated Waveshare 4.3B without case, stationary original 01 River Stone. **CAD study, not a complete print or powered-build release.**

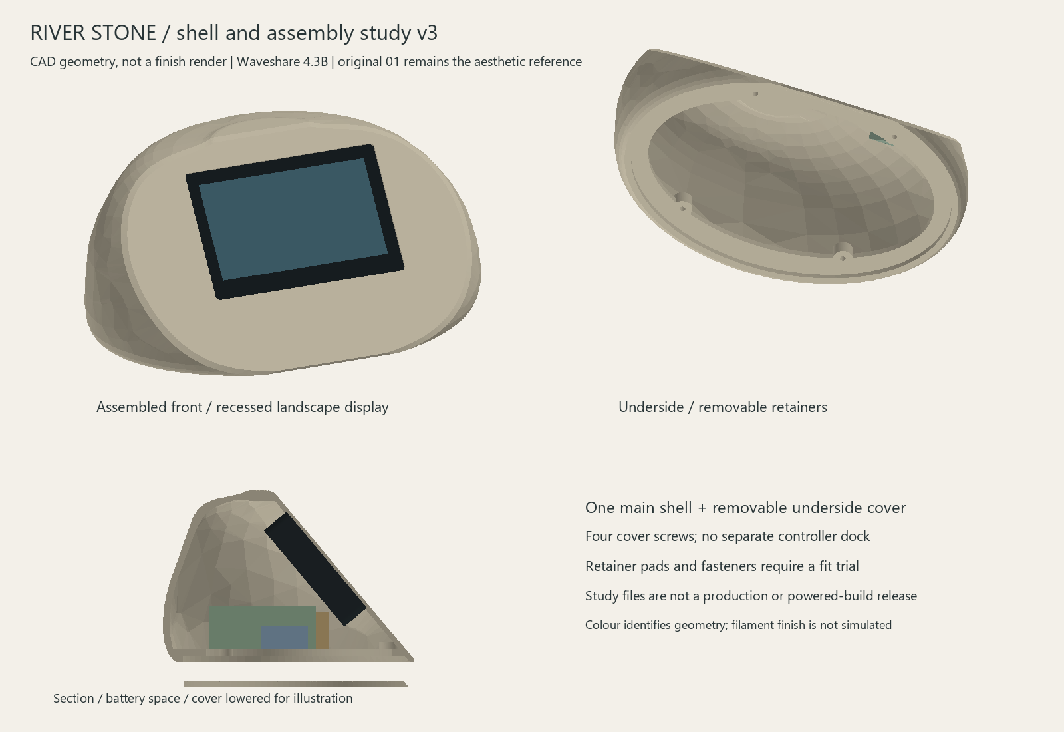
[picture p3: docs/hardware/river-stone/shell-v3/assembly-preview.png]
Revised shell


The lower rim is reinforced internally over its first 3.5 mm. Cover screw bosses now extend down to the ledge base at Z=3.5 mm, strengthening the junction beside their holes. The two upper cavity rings are lowered by 3 mm and its closing cap by 2 mm to add material beneath the crown. A 2 mm bevel now breaks the perimeter of the screen facet. This is a narrow chamfer, not the broad soft blend attempted in v2; further aesthetic refinement may still be needed against the original reference.

The shell remains approximately 220.1 x 151.1 x 103 mm. The matching underside cover is now 199.4 x 135.4 x 3 mm, reduced to clear the reinforced rim. Use the v3 cover with the v3 shell. The four cover fasteners, 50-degree display angle, side retainers and battery/power reservations retain their previous positions. The added shell material increases enclosed solid volume from about 206.3 to 229.8 cm3; this is not a slicer filament-volume estimate.

## Files

- [Shell STEP](shell-study.step) and [STL](shell-study.stl).
- [Matching cover STEP](cover-study.step) and [STL](cover-study.stl).
- [Assembly STEP](assembly-envelopes.step): includes retainers and conservative display/power envelopes.
- [Geometry validation](validation.json), [mesh validation](mesh-validation.json) and [print audit](print-audit.json).
- [Mount coupon](retainer-mount-coupon.stl) and [retainer coupon](retainer-strip-coupon.stl): unchanged from v2. See [fit-trial procedure and retention limitations](../shell-v2/README.md).

Seven exported meshes pass watertightness, consistent winding, positive volume, single-component and 256 mm cube checks. The fixed bosses and reinforced shell still clear the continuous conservative display-insertion path with retainers removed. Seated display, cover, glass/PCB proxies and component reservations pass the applicable collision checks. Actual cables, connector details and glass contact/load are not proven.

## Print audit

A seeded audit of 10,000 area-weighted face-centre rays found an exit for every ray. Minimum sampled depth is approximately **1.000 mm**, at the intentional screen lip. No samples are below 1 mm using a 0.0001 mm numerical tolerance. The first percentile is 2.065 mm, fifth percentile 3.000 mm and median 3.912 mm. This removes the sub-1 mm findings from the delivered audit; it does not prove that every possible section exceeds that value.

An intermediate v3 check located a 0.746 mm junction beside a rear cover screw hole. Extending the cover bosses through the ledge resolved that sampled issue. The final report contains the hash of the checked STL, matching the mesh-validation report.

Downward surface area beyond the 45-degree criterion is approximately **13,795 mm2 underside-down** and **5,328 mm2 screen-facet-down**, excluding bed-contact triangles. Reinforcement has not made the shell support-free.

The audit samples inward normal rays from mesh face centres. It cannot certify the global minimum wall thickness or print strength. Overhang areas classify triangle normals; they are not support-volume or slicer predictions. The visible face would touch the bed in the facet-down orientation, so lower overhang area alone does not establish the best print orientation. The preview uses coarse flat triangle shading; that appearance is not the intended filament texture.

Full-shell slicing, retention fit against the actual board, gasket loading, battery restraint, connectors, microphone/antenna space and electrical integration remain open. First inspect and slice the small fit coupons on the P1S with the intended filament and 0.4 mm nozzle. No slicing or physical testing was performed in this revision.

## Regeneration

Dependencies: CadQuery 2.8.0; numpy/Pillow for rendering; trimesh with scipy/networkx for checks. The CAD, mesh and audit commands accept `--deps PATH` for a local dependency directory.

```text
python tools/river_stone_shell.py --revision v3
python tools/render_river_stone.py --revision v3
python tools/check_river_stone_meshes.py --revision v3
python tools/audit_river_stone_print.py --revision v3 --samples 10000
```

The generator preserves explicit v1/v2 options; v3 is the new default. Earlier revision artifacts remain unchanged except for documentation that makes regeneration versions explicit.

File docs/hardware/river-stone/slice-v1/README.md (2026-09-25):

# River Stone P1S slicing study and fit trial

> **PARKED FALLBACK — 25 September 2026 (D030).** This is Waveshare-specific work, preserved without changing its geometry/results. Active design is [iPhone 11 mounting](../iphone-mount/README.md); old printing/next-step instructions below are suspended. See [fallback status](../fallback-waveshare.md).

21 September 2026. Based on [shell v3](../shell-v3/README.md), dedicated Waveshare 4.3B and stationary original River Stone. Offline slicing completed; no printer connection, print, or physical fit test occurred.

## Small fit trial

Open [fit-coupons.3mf](fit-coupons.3mf) in OrcaSlicer to review the two sample parts and their generated toolpaths. [Combined STL](fit-coupons.stl) is also included for your preferred slicer. The source samples are unchanged v3 geometry, arranged with broad flat faces down. The combined STL contains two disconnected parts intentionally.

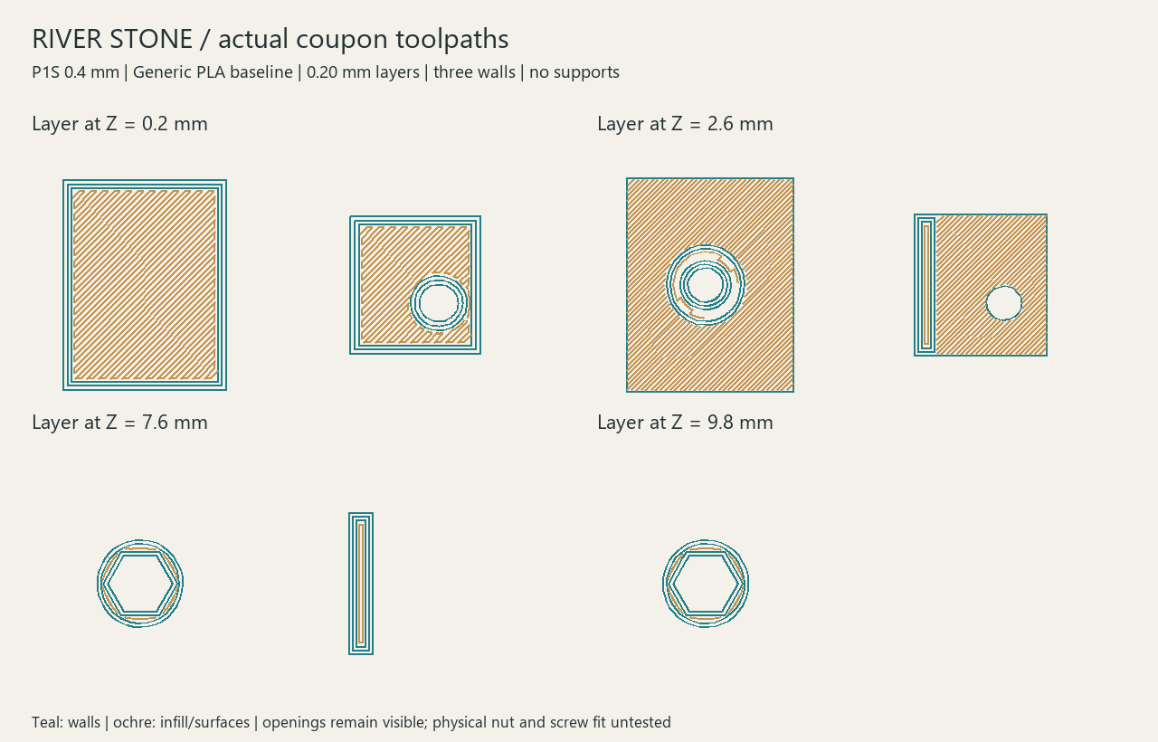
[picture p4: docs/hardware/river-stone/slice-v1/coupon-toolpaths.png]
Actual toolpath samples


The 3MF uses **P1S, 0.4 mm nozzle, Generic PLA, textured PEI, 0.20 mm layers, three walls and 15% infill, no supports or brim**. The inherited profile sets a 220 C nozzle and 55 C bed. Generic PLA and the plate are provisional assumptions for this study; check the actual spool and installed plate before printing or re-slicing. This is not a selected enclosure material or finish.

Slicer estimate: **15 minutes 49 seconds total, 2.73 g PLA**, 50 layers. Startup contributes approximately 6 minutes 16 seconds to that estimate. The coupon plate is within the P1S bed; exported metadata reports no outside-bed placement and no support use. Selected actual toolpaths were inspected at Z=0.2, 2.6, 7.6 and 9.8 mm. The screw passage and upper hex nut pocket remain open where intended. The mount coupon's bed-facing panel is intentionally blind, like its enclosure attachment face. Toolpath viewing does not establish dimensional fit.

All three slices retain Orca's `bed_temperature_too_high_than_filament` warning (1000C001, level 3). It occurred with the inherited Generic PLA/55 C textured-plate profile. This is recorded rather than hidden or described as a warning-free pass. Review the warning in the slicer against your actual filament and enclosure setup before printing. No temperature adjustment was validated physically.

After the small print, check that the intended nut seats without splitting the boss, the screw passes through the retainer coupon freely, and the pair can be tightened and removed by hand without stripping or bottoming. Record actual hardware dimensions, filament, plate, layer height and measured hole/nut fit. Keep glass out of this trial; the pads and actual Waveshare contact still require validation. A successful coupon does not release the full shell.

## Shell orientation comparison

Both orientations slice successfully with the same provisional PLA/P1S profiles and normal automatic supports permitted on the model as well as the bed. The shell profile keeps the no-brim baseline. These are baseline estimates, not optimized support settings or a final print orientation.

| Orientation | Estimated total time | Slicer filament estimate | Commanded support volume |
|---|---:|---:|---:|
| Underside down | 7h 43m 59s | 289.08 g | 74.44 cm3 |
| Screen facet down | 6h 18m 02s | 224.85 g | 21.84 cm3 |

Facet-down reduces the estimate by about 1h 26m and 64 g, but the visible front face contacts textured PEI and the bevel/shoulders still need support review. Underside-down keeps that broad visible face off the bed but uses much more support, including support in the hollow body. Removal access and marks remain physical questions. The two orientations therefore stay open until a surface sample establishes which leaves an acceptable result with little finishing.

Support volume is calculated from positive extrusion commands on XY/arc moves tagged as support or support interface, using the declared 1.75 mm filament diameter. It excludes Custom startup/purge moves and is not measured consumption. Total filament and time are Orca estimates. Independent support layers account for layer counts that can exceed height divided by 0.20 mm. Successful slicing does not prove support removability, print stability, strength, glass loading or finish quality.

The prepared orientation STLs and result summaries are retained here. Full-shell sliced projects/G-code remain in ignored local work folders; the full housing remains **not released for printing**.

## Reproducibility and sources

- [OrcaSlicer 2.4.2 official release](https://github.com/OrcaSlicer/OrcaSlicer/releases/tag/v2.4.2), Windows x64 portable archive; its checksum is in [source.json](source.json).
- [Official CLI documentation](https://github.com/OrcaSlicer/OrcaSlicer/wiki/cli_mode).
- Flattened profiles derive from Orca's bundled BBL profiles: `Bambu Lab P1S 0.4 nozzle`, its compatible `0.20mm Standard @BBL X1C`, and `Generic PLA`. Inheritance is resolved before the documented overrides. The profile names identify their base; the process settings are modified as listed above. The bundled [AGPLv3 license](profiles-LICENSE.txt) is retained for this third-party material. The slicer binary is not committed.
- [Coupon result](fit-coupons-result.json), [underside-down result](shell-underside-down-result.json), [facet-down result](shell-facet-down-result.json), [toolpath and warning review](toolpath-review.json). Hashes tie each result to its geometry, profiles and local G-code.

Run from repository root with Python, trimesh/numpy and Pillow installed:

```text
python tools/prepare_river_stone_slice.py --slicer-zip PATH_TO_OFFICIAL_PORTABLE_ZIP
python tools/slice_river_stone.py --slicer PATH_TO_ORCA_EXE --job fit-coupons
python tools/slice_river_stone.py --slicer PATH_TO_ORCA_EXE --job shell-underside-down
python tools/slice_river_stone.py --slicer PATH_TO_ORCA_EXE --job shell-facet-down
python tools/review_river_stone_toolpaths.py
```

Preparation accepts `--deps PATH` for the local trimesh installation. Slicing runs without a visible window and writes no commands to a printer. G-code timestamps mean a regenerated checksum may differ even when the settings and geometry match.

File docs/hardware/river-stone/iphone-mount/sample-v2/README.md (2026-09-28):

# iPhone aperture fit sample v2

28 September 2026. Open, hand-supported sample for the accepted **138.9 × 63.7 mm / R3 aperture with 6 mm overlap**. Original 01 River Stone remains the exterior reference; this test fixture does not define the stone silhouette.

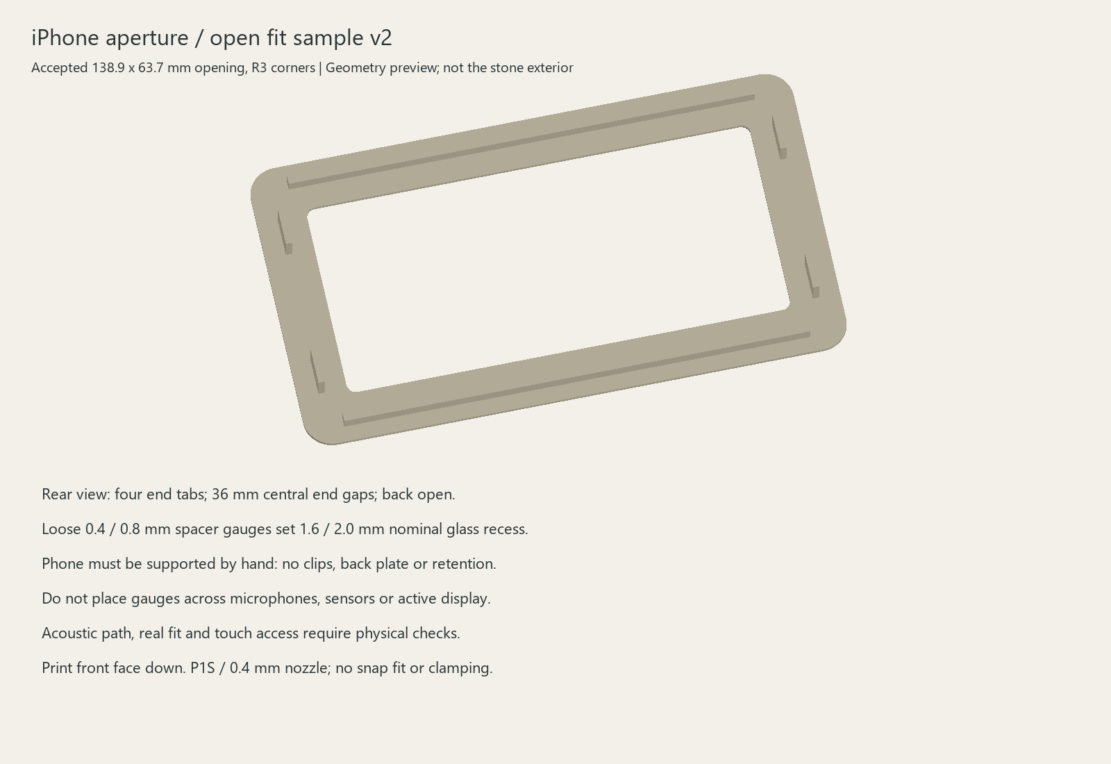
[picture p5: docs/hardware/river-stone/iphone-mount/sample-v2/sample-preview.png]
CAD rear view


## Files and printing

- [Frame STL](aperture-frame.stl) / [STEP](aperture-frame.step).
- [0.4 mm spacer gauge](spacer-0.4mm.stl) and [0.8 mm spacer gauge](spacer-0.8mm.stl). Duplicate four of the chosen thickness in the slicer. Do not mix thicknesses.
- [Solid checks](validation.json) / [STL checks](mesh-validation.json).

P1S with 0.4 mm nozzle. Trial starting point: familiar plain PLA, 0.2 mm layers, three walls, front face flat on the bed as exported. Use the normal profile for the actual filament and plate. Inspect sliced layers and spacer adhesion. No slice, time estimate or G-code is validated here.

Frame: 170 × 95 × 9.2 mm. Lip: 1.2 mm. Four end-locating tabs added; back remains open. Two long-edge stiffeners have a 79 mm inner gap versus nominal 75.7 mm phone width. The existing long rails remain unchanged. End tabs are 2 mm thick × 12 mm long × 8 mm high above the lip, with inner faces 152.9 mm apart: 1 mm nominal clearance at each end of the 150.9 mm body. Two tabs per end leave a 36 mm central opening above the lip. These are deliberately loose locators, with no snap-fit, overhang or back clamp. Exact button, microphone and camera clearance is not verified. Geometry is designed to grow from the flat flange without unsupported overhangs.

## Trial

1. Inspect for burrs, flatness and dimensional error before bringing the print near glass. Do not force the phone between rails.
2. Support the phone by hand from behind: **there is no retention**. Keep the rear camera, microphones, connector and buttons clear; do not rest the rear camera on a worktop.
3. Centre the accepted paper mask to register the opening. Select four spacer positions on the actual non-display perimeter, away from microphones, sensors and buttons. Positions are deliberately not fixed in CAD. Do not place gauges on active pixels. If safe positions cannot be established, hold the frame clear and report that before adding retention.
4. Compare 0.4 mm spacers (1.6 mm nominal glass recess including the lip) and 0.8 mm spacers (2.0 mm recess). Added protective film or padding increases the gap. Final recess remains unselected.
5. Check corner concealment, alignment, edge touch access and seated/oblique views. Keep cable plugs clear of microphone openings.
6. Check straight rear insertion/removal and record side-to-side movement. The nominal free movement is 2 mm along the phone length and 3.3 mm along its width; keep the phone centred for aperture assessment. Confirm each tab clears the real hardware, not just the nominal body. The central gaps reserve access but are not measured microphone keep-outs.
7. Compare bare-phone and sample-mounted voice recordings at the same orientation and distance using the intended app and existing Voice Memos/front/rear camera checks. Do not add continuous gasket or tape across inlets. An open back or narrow gap alone does not prove an unobstructed acoustic path.

Production retention, screw stops, padded supports and acoustic passages follow actual hardware mapping. This sample tests aperture/lip access and rear-loading space; it is not a finished cradle and does not validate the eventual closed stone's acoustics.

## Verification

Three valid CAD solids; zero intersection between accepted aperture cutter and frame. The nominal body box at the shallowest spacer setting does not intersect the frame. Both 36 mm central end channels are clear above the lip. These checks exclude protruding buttons/camera, cable plug and acoustic performance. All three STL meshes are watertight, consistently wound, single-component and fit within 256 mm. Preview comes from actual CAD tessellation. No physical printing or voice test claimed.

Reproduce with tools/iphone_mount_sample.py --deps followed by the CadQuery dependency directory; tools/check_iphone_mount_sample.py --deps followed by the trimesh directory; and tools/render_iphone_mount_sample.py. Python 3.12 with CadQuery 2.8, NumPy/Pillow and trimesh was used. Pass --revision v2 to all three tools (the current default); --revision v1 reproduces the earlier sample.

## Revision scope

User authorized short locating tabs at both ends to obtain more fit data in one print. Aperture, corner radius, flange, long rails and spacers are unchanged. The original [v1 sample](../sample-v1/README.md) is preserved. Use v2 for the next print; the two spacer meshes are identical to v1 and need not be reprinted if already available. This fixture still requires hand support and does not lock the phone in place.

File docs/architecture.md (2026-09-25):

# Architecture

> **D030 update — 25 September 2026:** iPhone 11 + selected UGREEN power bank replace Waveshare as active physical hardware. [Mounting/interface proposal](hardware/river-stone/iphone-mount/README.md) is under discussion. Earlier Waveshare hardware/UI implementation details below are retained fallback; native playback and bridge security requirements remain. This physical-design update does not implement or approve the entire iPhone software/power draft.

## Detailed-design status — 21 September 2026

D017 selects Waveshare ESP32-S3-Touch-LCD-4.3B without case and rules out Android. D018 specifies a provisional embedded-controller/always-on-bridge partition; Pi reuse depends on private host inventory. See [deployment design](deployment-design.md) for credentials, pairing, renewal and recovery gates, and [phase plan](detailed-design-plan.md) for dependencies. The development-host v1 bridge, secure storage/recovery, desktop contract harness and native LVGL fixture foundation are implemented; see [M2 software](m2-software.md) and [contract](controller-contract-v1.md). The ESP32 HTTPS worker is implemented and compiled; protected provisioning, on-device networking, Pi hosting and physical validation remain open. The optional/direct paths below describe feasibility-era architecture, not the current deployment recommendation.

## Required playback path

```mermaid
flowchart LR
    UI[Native 800 x 480 controller] -->|Authenticated HTTPS| PI[Always-on bridge: development host; Pi conditional]
    PI -->|Native commands and metadata| NDX[Naim NDX 2]
    TIDAL[TIDAL service] -->|Native Naim audio retrieval| NDX
    NDX --> AMP[Existing Naim amplifier]
```

This is the intended architecture. The solid local control path was exercised from a computer; the native firmware fixture compiles and the shared LVGL UI passes a desktop TLS fixture flow, and Pi deployment remains conditional. Network packets to TIDAL were not independently captured, but the live native endpoint, native queue class and player source identified the Naim TIDAL path. The test process fetched no audio.

## Responsibilities

**Controller:** rendering, touch input, local UI state, cached artwork, sleep/wake policy and battery monitoring. It sends high-level requests and rechecks actual device state after reconnecting.

**NDX 2:** native music retrieval and decoding, native queue and playback state. Existing amplifier integration must be preserved.

**Bridge (provisional D018):** provider credentials, search/collection adapters, artwork processing, voice/AI and native Naim commands. Development-host implementation exists; the Pi is a conditional hosting option after inventory. Home Assistant's web page is reachable; no authenticated HA integration has been inspected or installed.

## Observed local interface

The tested NDX 2 exposes HTTP port 15081, API 1.4.0 and appVer 3.11.0.5662. Firmware changes could affect behaviour.

| Operation | Observed request or reference |
| --- | --- |
| System information | `GET /system` |
| Input descriptions | `GET /inputs` |
| Current playback | `GET /nowplaying` |
| Native queue | `GET /inputs/playqueue` |
| Favourites | `GET /favourites` |
| Native content | Returned `inputs/tidal/artists/...`, `albums/...`, `playlists/...`, `tracks/...` references |
| Single native track playback | `GET /inputs/tidal/tracks/{returned-id}?cmd=play` |
| Stop request | `GET /nowplaying?cmd=stop` |

Some GET requests mutate playback. HTTP method alone is not a read-only guarantee. The diagnostic tool uses a fixed command-free allowlist.

Native playback reports `source=inputs/playqueue`, `sourceDetail=tidal`; the queue item class was `object.track.tidal`. Merely seeing playqueue is not enough to identify the music source.

Do not assume every duration uses the same units: the track description returned seconds, while now-playing duration and advancing position appeared in milliseconds. Negative position occurred during startup. Production parsing needs explicit per-field handling and tests.

## Extensibility

Separate UI requests from service adapters and Naim player commands. Future providers must satisfy the same native-playback requirement. Avoid building a universal audio server as a shortcut. Native queue edits and wired System Automation amplifier control have passed live tests. Search uses the project’s public TIDAL catalogue adapter. Native search syntax is not required by this prototype; long-running authentication renewal and recovery remain deployment validation work.

## Catalogue metadata prototype

The computer-side UI uses a loopback-only Python bridge in tools/prototype_ui.py. It runs a labelled demo by default; optional live catalogue and NDX configuration use the existing adapters. This is an implementation aid for the chosen display, not a committed Pi deployment or ESP32 firmware architecture. See [prototype scope and validation](prototype-ui.md).

tools/tidal_catalog.py implements public TIDAL catalogue search separately from native Naim playback. It uses this project's own developer credentials, sends only metadata requests, and returns candidate native IDs for subsequent resolution on the NDX. It does not import Naim credentials, fetch playback manifests or transfer audio. Credentials and tokens stay in the computer/Pi process; provider secrets will not be deployed to the controller (D018). Live search and pagination pass for artists, tracks, albums and playlists. Public search → native track resolution → playback has passed through the UI. AI discovery supplies catalogue queries only; see [voice discovery](voice-discovery.md).

## Account collection and phase boundary

The prototype also uses the project’s own TIDAL OAuth authorization for collection read/write, with exact album/artist metadata links and native resolution before playback. See [collection integration](tidal-library.md). The computer bridge is a proven reference implementation, not a selected final deployment. Software feasibility is closed; [the handover](milestone-handover.md) governs detailed design and records the remaining reliability and hardware gates.

## Approved UI implementation boundary — 22 September 2026

D020 approves the [desktop design](ui-review/approval.md). Its core screens and interactions are now ported to the shared C/LVGL renderer and bounded state model. The browser board remains a design artifact, not ESP32 runtime. [Native parity and evidence](m2-ui-parity.md) records the metadata/collection/voice extensions, current desktop tests and firmware compilation, and remaining artwork/device integration. Native adapter semantics and the separate physical acceptance gates are unchanged.

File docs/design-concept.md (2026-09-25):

# Coffee-table controller — design concept

> **D030 update — 25 September 2026:** iPhone 11 + selected UGREEN power bank replace Waveshare as active physical hardware. [Mounting/interface proposal](hardware/river-stone/iphone-mount/README.md) is under discussion. Earlier Waveshare hardware/UI implementation details below are retained fallback; native playback and bridge security requirements remain. This physical-design update does not implement or approve the entire iPhone software/power draft.

Revision 0.2 — 20 September 2026. Published baseline for parts investigation and the first UI prototype.

## Selected screen for the concept

**Waveshare ESP32-S3-Touch-LCD-4.3B, standard version without case (SKU 27848).** Use its 4.3-inch colour IPS touchscreen and 800 × 480 landscape canvas as the working prototype baseline. ESP32-S3, Wi-Fi and touch are integrated. This is the user's preferred prototype selection; hardware validation and final purchase selection remain open.

This replaces the earlier approximately square e-paper screen assumption. The physical direction is now the original 01 River Stone, stationary on the coffee table; see D014. The enclosure follows the actual display assembly, rather than forcing square proportions.

See the [manufacturer's display documentation](https://docs.waveshare.com/ESP32-S3-Touch-LCD-4.3B) and the maintained [hardware design](hardware/design.md) for specifications and mechanical references. The [parts BOM](hardware/bom.md) is the authoritative component list; this concept does not duplicate prices or connector specifications.

## Physical character

The original 01 River Stone: a low asymmetric pebble with inset landscape display and a refined mineral surface. It stays on the table; there is no separate handheld controller. The [dimensioned packaging study](hardware/river-stone/README.md) proposes a 220 x 155 x 105 mm envelope and 50-degree screen angle, both provisional. A substantial rechargeable battery sits low in the base, contributing stability and weight. The base is non-slip, the glass has perimeter protection, and a removable underside gives access to the battery and electronics. Final dimensions, fasteners, wall thickness and charging access follow component measurements.

Cable-free coffee-table use remains mandatory. A discreet rear cable charging inlet is the working proposal; controller-to-base charging is outside the stationary design. Weeks of standby remains an unmeasured target. With the selected LCD, standby means the screen turns off. Touch wake and whole-board consumption must be demonstrated; an always-visible now-playing screen has a separate energy budget.

## First UI prototype

- **Now playing:** prominent album artwork, track and artist, source, transport and queue access.
- **Find music:** touch-sized search field, artists/albums/tracks/playlists filters and ranked result rows; selecting an item opens a detail view before play or queue actions.
- **Collection:** native Naim favourites and their children, preserving the streamer's returned references.
- **Queue:** current queue inspection and clear feedback for additions. Do not display a requested change as a confirmed playback result.
- **Wake and reconnect:** retrieve fresh player state. When disconnected, show that state and leave browsing available where possible.

Use 800 × 480 as the design canvas, with large controls and restrained warm accents on charcoal. A computer browser is a software prototype only: it cannot validate touch accuracy at physical size, LCD power, ESP32 frame rate or wake latency.

The first UI excludes amplifier volume until the actual System Automation command passes an audible test. The user subsequently requested voice and natural-language AI discovery, now included in the computer prototype. See [voice discovery](voice-discovery.md) for behaviour and outstanding microphone hardware work. The palette stays adjustable to the final enclosure material.

## Required software path

TIDAL catalogue metadata → resolve the chosen reference through native Naim browsing → native Naim play/queue command → verify player state. The NDX 2 retrieves and decodes the audio. The controller and optional Pi carry commands and metadata only.

Public catalogue search and pagination have passed live tests. Native collection playback, queue commands and 24-bit playback have also passed independently. Combining a public search result with native playback has now passed through the UI on the home network. Full personalized TIDAL functionality is not yet established.

## Independent investigation tracks

| Track | Inputs now available | Evidence needed before final selection |
| --- | --- | --- |
| Display and embedded UI | Exact Waveshare candidate; 800 × 480 canvas | Touch usability, rendering, wake behaviour and firmware pin availability |
| Battery and power | Large protected pack in base; existing onboard power path to assess first | Whole-board active/sleep measurements, charging rate, shutdown and runtime |
| Enclosure | Original River Stone, stationary, serviceable underside, low battery placement | Actual board/connector/pack dimensions, antenna clearance, stability and fit |
| Software | Catalogue and native clients; working live evidence | Search-to-native handoff, app coexistence, recovery and audible amplifier control |

Record parts and research in [Hardware](hardware/README.md), accepted changes in [Decisions](decisions.md), and measurements in [Evidence](evidence.md). Parts research can proceed alongside the UI; final purchases and enclosure CAD still follow the software feasibility gate.

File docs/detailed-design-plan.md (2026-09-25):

# Detailed design and hardware proof

> **D030 update — 25 September 2026:** iPhone 11 + selected UGREEN power bank replace Waveshare as active physical hardware. [Mounting/interface proposal](hardware/river-stone/iphone-mount/README.md) is under discussion. Earlier Waveshare hardware/UI implementation details below are retained fallback; native playback and bridge security requirements remain. This physical-design update does not implement or approve the entire iPhone software/power draft.

Started 20 September 2026. Updated 21 September: parallel M2 software implementation is now present; see [implementation, validation and hardware-arrival checklist](m2-software.md). No hardware or Pi deployment proof is claimed.

**Scope update, 21 September 2026:** Waveshare ESP32-S3-Touch-LCD-4.3B without case is selected; Android is ruled out (D017). The [comparison](hardware/display-comparison.md) is retained as history. HP-01 is the first hardware experiment; purchase and hardware proof remain outstanding.

## Reference and audit

The annotated tag `software-feasibility-v1` resolves to commit `aa070fc0af4a616f769a7c0f15790831c90c112c`. At the original phase-entry audit HEAD matched that commit; subsequent documentation and packaging commits extend it. Preserve the tag and computer prototype as the comparison reference; do not redesign its playback route or restart feasibility research.

Read together: [handover](milestone-handover.md), [decisions](decisions.md), [architecture](architecture.md), [hardware index](hardware/README.md), and all five documents linked by that index. The audit also inspected collection/voice documentation and the bridge/token adapters. Findings:

| Area | Established in repository | Unresolved / next deliverable |
| --- | --- | --- |
| Playback and amplifier | Computer-side native TIDAL, queue operations and bounded wired System Automation proven | Preserve adapters and D011 semantics; exercise integration/recovery, not a new audio path |
| Display | HW-001 exact preferred model recorded; manufacturer references only | Actual revision, physical usability, memory/render load, accessible pins and touch wake |
| Energy | Wh model and candidate external power route exist; no measurements | Whole-board standby and wake energy before battery sizing; no weeks-of-use promise |
| Power components | Onboard large pack on hold; external charger/boost shortlisted | Net-level revision review, low-load losses, peak/thermal limits, isolation and backfeed |
| Voice | Browser capture/transcription proven | No microphone selected; bus/pin availability, capture amid music, acoustic opening and power |
| Deployment | Loopback HTTP server, in-memory credentials and refresh logic exist | Persistent secure service, controller authentication, renewal/revocation and recovery |
| Interaction | 800 × 480 browser proof | Physical target sizes, keyboard, wake contact, busy/unknown/error behavior |
| Packaging | Base battery and serviceable printed shell required | Measured parts, cable/insertion clearances, thermals and seated touch stability |

The packaging work originally inspected as untracked is now recorded in commit `ef2576c`: `docs/hardware/river-stone/` and `tools/river_stone_layout.py`. Their README records a selected stationary River Stone concept and P1S/0.4 mm manufacturing constraint. Carry that direction into packaging review without reopening aesthetics. Its dimensions/reservations are proposals, not fit or electrical evidence. The phase plan does not release that layout for manufacture.

Two stale records described amplifier control as unresolved; the BOM and R10 now point to D011. No physical cable identification or new cable purchase is implied. The deferred browser discrepancy is B01 below; its cause is unknown.

## Work packages and gates

Sequence: P0 → P1; P2 and P3 specification can proceed during P1; P1 + P2 + P3 → P4 → P5. Procurement is separate from design approval. Time estimates depend on equipment availability; no purchase is recorded or authorized by this plan.

| Work | Deliverable | Dependencies | Acceptance / stop condition |
| --- | --- | --- | --- |
| P0 — bench readiness | HW-001 availability, equipment inventory and dated purchase proposal if needed | Existing BOM | Exact selected 4.3B without case; suitable supply/measurement equipment; purchasing approval before ordering |
| P1 — screen/touch/power proof | [Waveshare HP-01 report](hardware/first-experiment.md), reproducible firmware/build settings and sanitized traces | P0, revision-matched schematic/example review | Usable screen, repeated touch wake and measured power states; diagnose failures before integration |
| P2 — deployment proof | [Deployment design](deployment-design.md), host suitability record, service/config/recovery tests | Read-only Pi inventory; no existing HA workload changes without a concrete migration plan | Secure restart restores authorization; renewal, revocation, controller pairing and lost-command recovery pass; HA workload remains healthy |
| P3 — interaction and microphone | [Physical UI trial](interaction-design.md), task results; pin/bus budget and microphone capture report | P1 display; fixture bridge available before P2 deployment | Core tasks usable at actual size; transcript review/cancel works; recording stops on exit; microphone capture under display/Wi-Fi load succeeds |
| P4 — power selection | Measured battery-side energy budget, selected pack/charger/converter and wiring drawing; revised BOM | P1 loads, P3 microphone load, agreed use profile | Peak margins, standby budget, charge/use thermals, low battery and service isolation pass against chosen component ratings |
| P5 — fit and integrated prototype | Measured component CAD, bezel/mount sample, serviceable fit print and integration report | P1 dimensions, P3 acoustics, P4 selected parts | No glass point loads/pack compression; insertion and service paths work; charging, RF, heat and touch stability pass in housing |

P2 starts with a thin controller UI plus an always-on metadata/control bridge as the working architecture. Use embedded UI firmware on the selected Waveshare; Android work is retired. Reusing the existing home-automation Pi is preferred conditionally, not an assertion that its OS supports the service. See deployment gates before installing anything. A separate host is a fallback only if resource/isolation constraints require it; no new host purchase now.

## Parallel software preparation

While hardware is unavailable, the next software task can implement a development-host bridge, fixture-backed controller contract, recovery/security tests and an embedded UI/build foundation using the selected Waveshare assumption. This extends parallel preparation beyond specification; it does not pass P1, physical P3 or Pi deployment acceptance. Keep hardware-specific interfaces replaceable and distinguish simulation, compilation and live observations. Implementation started after repository cleanup: protected bridge state, authenticated TLS fixtures, navigation/recovery and native UI/build sources are now available. The shared desktop LVGL TLS flow, two native C tests and ESP32 fixture compilation now pass; provisioning and on-device network validation remain open. P2 software tests proceed independently of P0/P1; host suitability and physical gates remain open.

## First practical action and evidence discipline

Execute HP-01 on the selected Waveshare using USB power before connecting a large battery. It tests touch wake, standby consumption and recovery. Confirm board and instrument availability first; until hardware is available, complete revision-matched schematic review and prepare the build recipe. A desktop demo is not hardware proof.

Store private captures, host inventory, addresses, receipts and recordings under ignored `local/`. Commit sanitized summaries with date, board revision, firmware commit/build configuration, instruments, measurement boundaries, durations, failures and raw-evidence location. Add conclusions to [evidence](evidence.md) only after observation; update decisions and roadmap at each gate. A failed gate is useful evidence, not grounds to silently change native playback or touch-wake requirements.

## Backlog and unresolved user choices

| ID | Item | Trigger / disposition |
| --- | --- | --- |
| B01 | Album-save visibility differed between laptop browser and Codex preview; cause was not documented | Deferred. Investigate only if it blocks a deployment/UI acceptance task or the user requests it. Record exact build, mode, origin, account authorization and reproduction in both contexts then; do not assume caching or apply a speculative fix |
| B02 | Gaplessness, higher sample rates, Naim-app concurrency and real outage recovery | Schedule coexistence/outage checks in P2 integration; quality checks only when relevant. Preserve existing partial evidence |
| B03 | Queue-edit UI, playlist creation/editing, shuffle/repeat/seek and additional row hearts | Prioritize explicitly after core P3 task trial; no feature-parity expansion in this phase |
| B04 | Daily use and recharge target | Before P4 sizing agree active minutes/day, visible-display listening hours, standby weeks, wake tolerance and recharge duration. Use existing 15/30-minute and 28-day scenarios only as assumptions |
| B05 | Dock, ballast, e-paper alternative | Deferred unless measured charging convenience, stability or LCD energy failure makes one relevant |

Hardware availability is the immediate information dependency. Pi OS/install type/resources are the next deployment dependency. Purchasing, a host migration or a measured requirement tradeoff needs a concrete proposal for user decision; reversible documentation and fixture work continue independently.

## Current continuation — 22 September 2026

Desktop UI design is approved (D020). [M2 closeout](m2-closeout.md) records delivered software, prior validation and remaining gates; [the continuation prompt](continuation-prompt.md) starts the approved shared-LVGL implementation. The subsequent [native port](m2-ui-parity.md) implements the core layouts, Settings/detail navigation and immediate-record Stop & search, with integration limits recorded explicitly. This checkpoint does not close HP-01 or physical P3/P4/P5.

## Shared approved UI implementation — 22 September 2026

The approved direction is now implemented as native C/LVGL slices: Playing layout and controls, filtered search, nested details and membership, collection/queue reads, immediate-record voice search and Settings. See the [parity inventory and actual evidence](m2-ui-parity.md) for implemented behavior and remaining integration gaps. Desktop evidence: 72 Python tests, five JavaScript tests, two CTests, five-stage TLS demo and expanded native LVGL/TLS smoke passed. HP-01 and physical P3/P4/P5 remain open; the hardware-arrival checklist is unchanged.

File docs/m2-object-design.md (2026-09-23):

# River Stone: native design for the object

> **Current status — 23 September 2026:** Work is paused at the user's request. The working prototype is retained, but its visual direction is not accepted. Earlier approval/gate/next-step statements below are historical and do not authorize further design work. Read [the chat closeout](chat-closeout-2026-09-23.md) and D028; resume only under the user's revised direction.

23 September 2026. D027 supersedes treating the rough approved browser prototypes as a final visual constraint. The target is a deliberate listening-room object: calm in the original mineral pebble enclosure, readable when approached on the coffee table, and recognizably music-first rather than a diagnostic terminal.

## Iteration and judgement

1. Enlarged the Playing artwork from 240 to 280 px, rebalanced the right column, reduced permanent status/quality clutter and replaced boxed navigation with quiet labels and a short selection accent. The first native matrix exposed an unlaid-out fixture cover and clipped long track titles. Gate: fail.
2. Corrected cover sizing, bounded the title to two lines with ellipsis, retained readable cached metadata, and made offline plus uncertain outcomes explicit. Reviewed sage/sand/slate, paused, missing artwork, long text, lists, Settings and detail screens. The primary transport still needed stronger emphasis and browse titles needed more presence. Gate: revise.
3. Added a restrained tonal disc and heavier Play/Pause mark while retaining 80 x 64 px targets; enlarged list/search type to 24 px and quietened the query border. Reviewed the final matrix and exercised native pointer paths. Gate: pass for desktop composition and state clarity, subject to the separate limits below.

The judgement is that the screen now belongs more naturally in the enclosure reference: a large visual anchor, quiet mineral colours, generous spacing, clear music hierarchy and restrained controls. This is a designer assessment, not a measured aesthetic score or a claim that the user has approved the result.

## Desktop gate

| Criterion | Evidence / result |
| --- | --- |
| Music leads the composition | 280 px cover, 32 px title, 24 px artist; source and secondary metadata recede. Normal connection text and missing bitrate no longer occupy the music area. Known bitrate remains visible below the cover. |
| Clear primary interaction | Play/Pause has a subtle disc and stronger glyph; next/previous and amplifier controls remain separate with no repeat behaviour. |
| Readable palette hierarchy | Native-exported roles give primary contrast 12.42-13.63:1 and secondary contrast 6.96-7.36:1 against their screen backgrounds. These are sRGB calculations, not LCD measurements. |
| No title collisions | Long track names truncate cleanly over two lines; browse rows use ellipsis and separate artist/type subtitles. |
| Honest abnormal states | Missing real artwork stays unavailable. Offline, uncertain and pending states remain explicit; unavailable mutations are disabled. Cached metadata remains legible. |
| Consistent secondary screens | Outline icons, palette roles, larger browse text, structured settings and coordinated controls reviewed in actual LVGL pixels. |
| Generous distinct targets | Native gate checks all five transport/amplifier targets are at least 72 x 64 px, within the content band and non-overlapping; current targets are 80 x 64. Physical touch is not established. |
| Reproducible review | `python tools/m2_visual_review.py` renders 13 native states, converts captures and builds an ignored review board plus contrast report under `local/m2/design-review/`. The C executable uses synthetic state and the production renderer, with no network/mutation path. |

## Demo content and real artwork

The standalone fixture has three original geometric sleeve studies drawn at display resolution, explicitly selected only by native `fixture:studyN` markers while fixture mode and freshness allow them. They do not replace absent/corrupt network artwork or bypass the authenticated image protocol. `Silent demo` remains visible. Synthetic tracks are A Still Morning, Soft Light and Quiet Hours by River Stone Ensemble; they produce no audio. TLS fixtures retain their authenticated artwork checks and explicit cover variant, independently of track display titles.

Production photographic artwork remains the prior bounded 80 x 80 preview. Enlarging its space does not improve its resolution. Higher-resolution authenticated delivery is still required before claiming finished photographic quality; this gate establishes composition and states using known synthetic content, not a finished live listening experience.

## Fresh verification

- Desktop build and six CTests passed, including the new native visual geometry/state matrix.
- All 128 Python tests passed. The first suite attempt hit the previously observed Windows loopback `ConnectionAbortedError` in unchanged origin-rejection coverage; the unchanged rerun passed. No security check was weakened.
- Full native SDL/LVGL plus silent authenticated TLS screen/artwork smoke passed, including Back, Play, voice, follow/library, settings and consumed wake contact.
- Standalone/TLS transport taps and icon pixels passed, with one command per tap and preserved track identity/wrapping.
- Separate-process preference persistence passed with updated palette pixels.
- Startup outage, delayed read, lost mutation response and restart recovery passed with one silent play and one simulated amplifier request and no replay.
- ESP32 build passed: `0x98810` bytes, 40% application partition free. Compilation only; no flash, efuse, physical action or live audio.

## Still outside this gate

Actual screen contrast, seated viewing distance, finger accuracy, glare, enclosure-material samples, LCD frame timing and power require physical trials. The documented display visible area has a slightly different aspect ratio from 800 x 480; inspect the actual panel rather than treating a desktop screenshot as a physical-size proof. No always-on ornament mode or battery-life claim is added. HP-01 and P3/P4/P5 remain open. Native TIDAL resolution, D011, protected state, authentication and no-replay rules are unchanged.

## Desktop input handoff follow-up

The first extracted design package timed out at native smoke stage 6 after a tap. Inspection found that SDL/synthetic press state could wait until the later LVGL input poll while a UI timer started a background read. Desktop input now reports contact immediately, before the timer pass; ordinary LVGL pressed/released delivery remains in place. It does not queue, retry or replay a mutation. Desktop rebuild/six CTests and the full native TLS screen/artwork/wake-contact sequence pass after this change. The earlier intermittent stage-21 result is historical; a shared root cause is not claimed. The replacement package must contain this later desktop executable; ESP32 sources and compiler evidence are unchanged.

## Final packaged gate

A further package run exposed two synthetic-driver assumptions: Search could be tapped before its read-dependent enable state, and a timed contact could expire before the input driver observed it during a slow draw. The smoke now waits for readiness where needed and holds one contact for 90 ms after driver observation; it never repeats a tap to force success. Desktop presentation also now copies/presents once per completed LVGL frame, rather than once per 40-line strip. This removes redundant software copies without claiming a measured frame rate.

After those corrections, the desktop build and six CTests pass. The extracted candidate package passes the full native TLS UI/artwork flow, isolated bundled runtime checks, side-by-side preservation of pairing/preferences, and standalone/TLS Play/Pause/Next/Previous pointer/pixel checks with one command per tap. The final clean-source archive is checked for payload identity with that tested candidate and manifest integrity. Earlier failed design/verified ZIPs are development attempts; deliver only the final package.

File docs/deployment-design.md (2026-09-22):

# Deployment design — initial selection

20 September 2026 design; implementation update 21 September. The [M2 software workstream](m2-software.md) implements authenticated development-host TLS, pairing/revocation, protected persistence, atomic/single-flight renewal and command recovery with synthetic tests. No Pi installation, live LAN deployment or networked ESP32 service client has been validated.

## Responsibility boundary

Use an always-on bridge for metadata, account authorization, artwork resizing/cache and voice/AI requests. D017 selects Waveshare with native ESP32 display/touch firmware (LVGL candidate, version to pin after example review). Do not assume the ESP32 runs the prototype browser. The computer UI/adapters remain the frozen behavioral reference.

Android browser/kiosk deployment is retired by D017. Pi host selection, authenticated controller transport and firmware credential protection remain open deployment gates.

The bridge sends native Naim commands; the NDX 2 retrieves and decodes TIDAL music itself. No music audio, playback manifests, relay or substitute route passes through the bridge. User-initiated microphone clips are voice input, not playback audio. Wired amplifier control retains D011: one press plus four held frames spaced 0.2 s, one bounded burst per tap, busy until completion, no automatic retry or numeric level.

Prefer the existing home-automation Pi if it supports an isolated service with adequate storage, RAM and CPU headroom and reliable uptime. Inventory OS/install type, runtime support, backups, resource use, network reachability and administrative access privately first. A supported container or dedicated service account may fit a general-purpose OS; do not assume Home Assistant OS accepts arbitrary system services. Select the packaging after inventory. Avoid an unnecessary Home Assistant integration dependency: the bridge can use the proven Naim adapters directly. If host constraints fail, present a separate-host proposal before migration or purchase.

This partition keeps provider secrets off the controller, avoids embedding cloud authentication and AI complexity in limited display firmware, and lets the controller sleep while native playback continues. Its cost is bridge availability: when unavailable, show unavailable/stale state and offer reconnect; do not invent an alternative audio path. No queued playback mutations during outage.

## Credentials and trust

- Persist provider configuration, OpenAI key and TIDAL refresh authorization only on the bridge, outside Git and the web root. Use OS-protected service credentials where supported; otherwise an owner-only service directory/files (directory 0700, files 0600 on Linux). Encrypt backups with separately managed keys; a key next to ciphertext is not protection from host compromise. Full-disk/offline protection depends on host capabilities and must be recorded.
- Access tokens can remain in memory. Persist refresh-token rotations atomically before reporting renewal complete; retain the old token only when the provider omits a replacement. Serialize concurrent refresh requests. File errors fail visibly rather than silently losing durable authorization. Test process interruption around replacement. Disconnect deletes durable local authorization and caches; account-side revocation remains separate.
- Pair each controller using a short-lived, single-use setup code approved at the local administration interface. Issue a revocable device credential with control-only privileges. Provider secrets never appear in firmware, browser responses, command arguments or logs. Controller credential storage and ESP32 flash protection remain an implementation gate; a physically extracted device credential must be individually revocable.
- Use authenticated HTTPS for controller-to-bridge traffic with provisioned trust; validate certificates and define renewal before deployment. No public port forwarding. Restrict listening/firewall exposure to intended local clients; LAN membership alone is not authentication. Browser administration also requires authentication, origin/CSRF defenses and bounded requests.
- Preserve OAuth state, PKCE and collection-only scopes. Register a supported exact deployment callback after host identity and the provider's current callback rules are checked. The existing loopback redirect cannot simply become a remote callback. Complete account login in a trusted browser, then return only status to the controller. Never work around this with captured Naim tokens.

Current evidence: the prototype binds `127.0.0.1`, constrains Host/Origin, stores tokens in memory and contains refresh logic. The separate M2 service now adds tested TLS/controller authentication and durable single-flight renewal. Neither implementation proves secure host deployment or long-running provider renewal.

## Recovery contract

| Event | Required behavior |
| --- | --- |
| Controller wakes/reconnects | Discard pending gestures/commands; reconnect, authenticate, fetch current source/transport/queue and account status; display freshness and mark cached artwork/state stale until reconciled |
| Bridge or NDX unavailable | Disable device mutations; keep browsing context; bounded read retries with exponential backoff/jitter (initial design 1, 2, 4, 8…30 s), immediate explicit reconnect available |
| Mutating command timeout | Outcome unknown; never replay playback, queue or volume automatically. Read state where possible. Volume has no reliable absolute read-back: show uncertainty without corrective burst |
| Duplicate controller request | Unique request ID and server duplicate suppression. On server restart, uncertain previously sent mutations remain unknown; do not claim exactly-once delivery across NDX/network failure |
| Account token expiry | Single-flight refresh before expiry; persist rotation. Transient provider failure is distinct from revoked/invalid authorization; bounded retries for reads/refresh only, no automatic collection write replay |
| Revoked authorization | Mark collection disconnected and offer explicit reconnect; native Naim playback remains independent of this account session |
| Saved-state read fails | Unknown state, not unsaved; preserve existing fresh-read/write-once/read-back semantics |
| Other Naim app changes playback | Refresh actual player/queue state; do not overwrite it from controller cache. Native state is authoritative |
| Bridge reboot | Restore protected configuration/token state, start without playback/volume commands, then reconcile; report unavailable until adapters ready |

Proposed active-state polling: 2 s now-playing, queue refresh on entry/known changes; back off errors and pause controller requests during sleep. Measure load and adjust before acceptance. Do not poll cloud collection continuously. Bound artwork dimensions/cache, voice duration/upload size and request concurrency; port proven adapter logic rather than exposing diagnostic scripts wholesale.

## Deployment acceptance

The shared native controller now has an asynchronous, bounded HTTPS transport implemented for ESP-IDF and an authenticated SDL desktop transport. The ESP32 source compiles; only the desktop path has executed against TLS fixtures. Default firmware is offline unless encrypted NVS, secure boot, flash encryption and provisioned host trust/device authorization are present. No efuse changes or real controller provisioning have been performed. The protected NVS field contract and pinned build commands are in [firmware instructions](../firmware/README.md); physical trust bootstrap, revocation and recovery remain acceptance work.

Produce fixture tests for restart/atomic rotation, concurrent renewal, revoked tokens, forbidden unauthenticated clients, expired setup codes, wrong server certificates, duplicate/time-out commands and sanitized logs. Then run a private host trial: restart bridge and controller; expire/renew authorization; disconnect Wi-Fi and NDX independently; alter playback in Naim app; recover without duplicate mutations. Exercise known bounded volume only as an announced audible test, never a CI step. Verify actual native playback state, not HTTP success alone.

Run a proposed 24-hour host coexistence trial including voice/search bursts; record resource use and Home Assistant health before/during/after. This is an initial integration gate, not production reliability proof. M4 retains long-duration operation and battery testing. Current host suitability, callback registration and ESP32 credential provisioning remain open. Pairing, revocation and durable bridge storage now have development-host synthetic tests; they do not establish Pi or physical-controller deployment acceptance.

## Settings design boundary — 22 September 2026

Approved Settings screens illustrate display preferences, Wi-Fi, pairing/revocation and device diagnostics. The browser review implements local fixture behavior only; it provisions no real network or credential. Native UI integration must use the protected provisioning/trust interfaces above and clearly report unavailable hardware capabilities. Approval does not close host selection or on-device deployment gates. See [continuation](continuation-prompt.md).

## M2 enrollment and revocation foundation - 22 September 2026

The [offline provisioning slice](m2-provisioning.md) adds protected enrollment intent, origin/trust-bound controller records, durable uncertain/revoked states, local ID inventory and setup-code cancellation. The desktop helper enforces new record bindings while preserving legacy fixtures. Fresh evidence: 93 Python tests, read-only TLS enrollment/revocation/re-pairing demo, native UI/artwork smoke and outage-recovery demo passed. No C/ESP32 or UI changes; prior build evidence was not rerun. Production setup UI, physical installation and HP-01/P3/P4/P5 remain open.

## Host setup console - 22 September 2026

The [operator setup flow](m2-setup.md) adds local status, hidden-code pairing, explicit read-only verification and confirmed local forgetting. It rejects piped secret input and echo fallback, retains durable unknown outcomes and supports local recovery without a trust file. Fresh evidence: 107 Python tests, setup/TLS fixture demo and enrollment regression demo passed; zero live commands or real credential changes. Native UI/firmware are unchanged. Physical terminal echo and deployment/hardware gates remain separate.
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

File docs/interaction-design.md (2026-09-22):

# 4.3-inch interaction trial

20 September 2026. Initial design specification for physical trials, not validated UI or a feature expansion. Preserve charcoal/sage/sand and tonal artwork from the reference.

D017 selects Waveshare and rules out Android. The 800 × 480 layout and external microphone investigation below are the active trial plan; actual panel usability remains unproven.
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

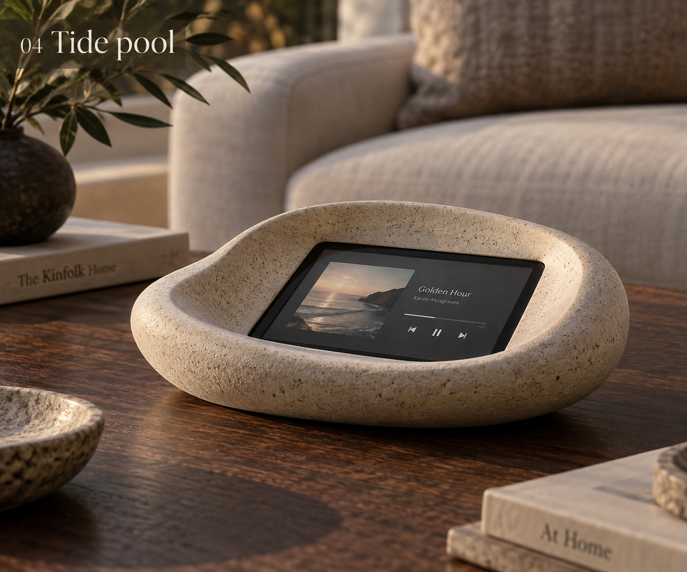
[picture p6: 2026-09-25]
docs/hardware/river-stone/iphone-mount/interface-reference.png

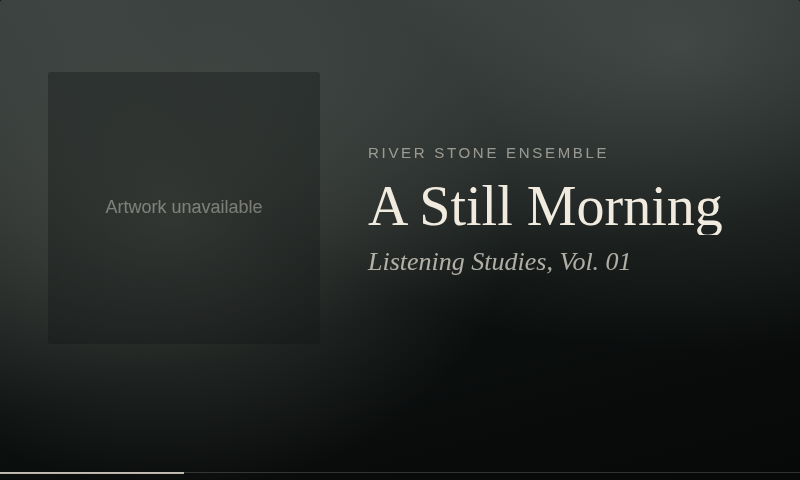
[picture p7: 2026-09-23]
docs/still-water/reference/16-noart.png

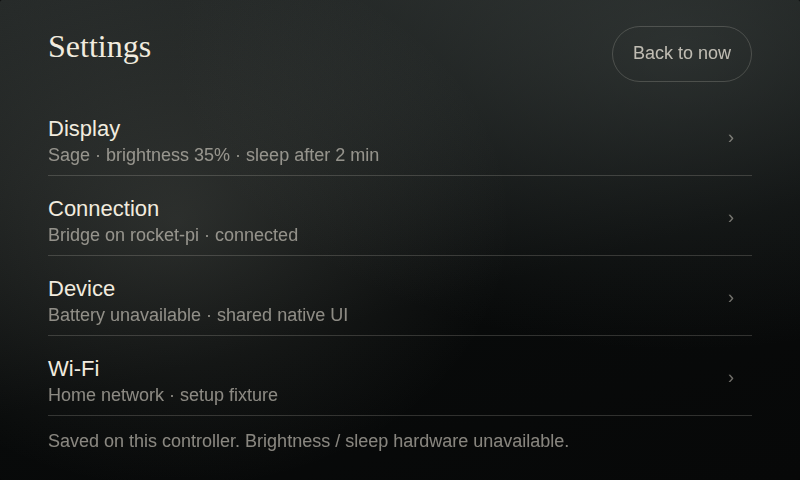
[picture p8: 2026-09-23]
docs/still-water/reference/21-settings.png

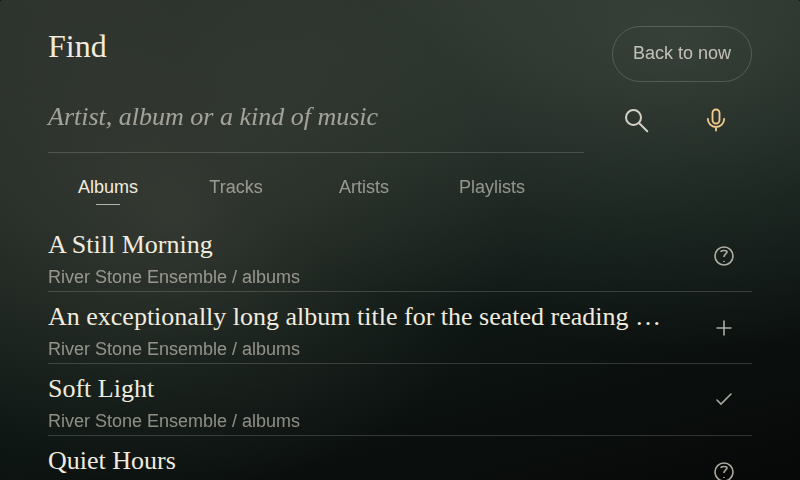
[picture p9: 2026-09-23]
docs/still-water/reference/17-find.png

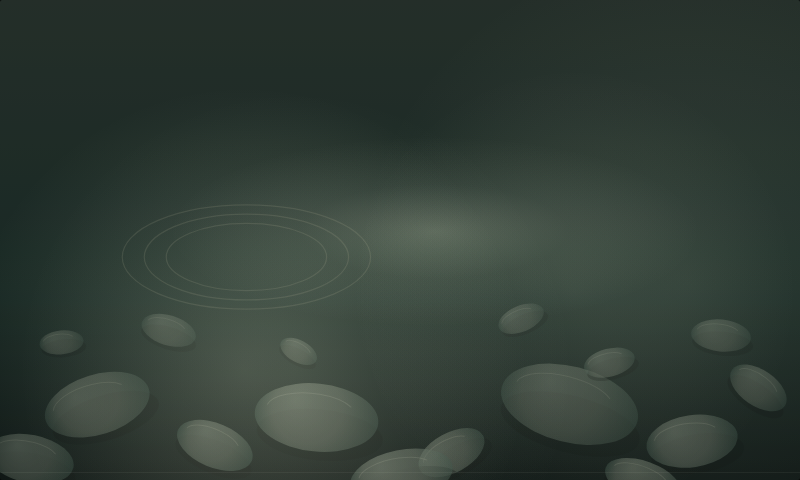
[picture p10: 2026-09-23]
docs/still-water/reference/03-presence-music.png

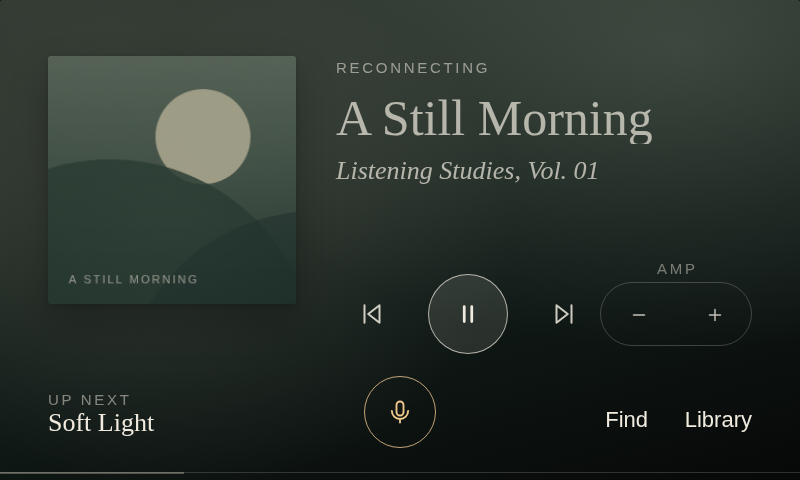
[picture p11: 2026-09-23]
docs/still-water/reference/12-offline.png

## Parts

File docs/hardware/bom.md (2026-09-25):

# Parts BOM

> **D030 update — 25 September 2026:** active hardware is iPhone 11 + selected UGREEN Nexode 20000mAh PD 20W QC Power Bank. See [current mounting and power packaging](river-stone/iphone-mount/README.md). Waveshare-specific parts, experiments and purchase recommendations below are fallback history; actual prior order records remain valid. This update does not cancel orders or authorize more purchases.

Revision 0.9 — 22 September 2026. Prototype procurement BOM; see [UK prototype shopping list](prototype-shopping-list.md) for supplier baskets, current quotes and purchase-readiness limits.
Six Pi Hut items are ordered, user confirmed 22 September: display, charger, converter, microphone and two harness parts. Delivery not yet confirmed. USB-C PSU, tools and wires are already owned. MicroSD sniffer is ordered from SK Pang, user confirmed 22 September; Pimoroni BAT0014 10,050 mAh battery is also ordered, user confirmed 22 September.

D017 selects HW-001 and excludes HW-019. Existing prices are historical references, not refreshed quotes or purchasing approval. Selection and procurement are separate.

## Procurement status — 22 September 2026

| Supplier / source | Items | Status |
| --- | --- | --- |
| Pi Hut | Waveshare bare 4.3B display; BQ24074 charger; U3V40F5 regulator; SPH0645 microphone; JST-PH lead; USB-A female breakout | 6 items ordered; delivery not yet confirmed |
| SK Pang | SparkFun microSD Sniffer TOL-09419 | 1 item ordered; delivery not yet confirmed |
| Pimoroni | BAT0014 protected 10,050 mAh battery | 1 item ordered; delivery not yet confirmed |
| Existing inventory | USB-C PSU, USB cable, tools and wires | Owned; no purchase needed |
| Remaining design work | Battery monitoring/low-voltage control, temperature probe, enclosure parts and final fittings | Not yet selected or procured; conditional items remain conditional |

Order status comes from the user's confirmation. **Ordered does not mean received, assembled or tested.** Final invoice totals, order references and delivery dates have not been supplied.

## Controller parts

| ID | Item / exact candidate | Qty per unit | Selection | Procurement | Price reference | Next action |
| --- | --- | --- | --- | --- | --- | --- |
| HW-001 | [Waveshare ESP32-S3-Touch-LCD-4.3B](https://www.waveshare.com/product/arduino/boards-kits/esp32-s3/esp32-s3-touch-lcd-4.3b.htm), standard without case, SKU 27848 | 1 | selected | ordered from Pi Hut, user confirmed 2026-09-22 | USD 36.99; 2026-09-20; shipping/tax excluded | HP-01 after procurement; validate revision, touch wake and power |
| HW-019 | Old Android phone | 0 | excluded | not applicable — excluded | Not included | Ruled out by user, D017; no further phone trial |
| HW-020 | Adafruit 3421 SPH0645LM4H I2S microphone | 1 | evaluation candidate | ordered from Pi Hut, user confirmed 2026-09-22 | Pi Hut £6.70 incl VAT, 2026-09-21 | [Microphone review](microphone-review.md); proposed microSD pin reuse requires validation |
| HW-021 | SparkFun microSD Sniffer TOL-09419 / SK Pang USD-SNIFFER | 1 | evaluation candidate | ordered from SK Pang, user confirmed 2026-09-22 | £8.52 incl VAT, 2026-09-21 | Experimental mic pin access; confirm delivery, fit and continuity |
| HW-022 | External battery-temperature NTC probe compatible with charger | 1 conditional | research | not ordered | Unquoted | Specify sensor curve and mounting; separate from bench thermometer |
| HW-002 | Pimoroni BAT0014 protected 10,050 mAh / 3.7 V pack | 1 pack | prototype selection | ordered from Pimoroni, user confirmed 2026-09-22 | Checkout showed £25 subtotal + £10.74 shipping + £7.15 estimated tax = £42.89; final paid amount unconfirmed | [Larger battery review](larger-battery-review.md): body fits reserved envelope; polarity, restraint and power tests pending |
| HW-003 | Adafruit BQ24074 4755 charger and power path | 1 | prototype selection | ordered from Pi Hut, user confirmed 2026-09-22 | Pi Hut basket £14.40 incl VAT | Validate delivered revision, charge rate, simultaneous use/charge and termination |
| HW-004 | Pololu U3V40F5 5 V step-up regulator, POL4012 | 1 | prototype selection | ordered from Pi Hut, user confirmed 2026-09-22 | Pi Hut basket £9.60 incl VAT | Measure idle losses and startup peaks; system low-voltage control remains unresolved |
| HW-005 | Battery state monitoring: onboard capability to investigate; external fuel gauge conditional | 0 or 1 extra board | research | not ordered | TBD if needed | Confirm voltage/status access and low-battery behaviour |
| HW-006 | Internal battery/power harness with keyed connectors and strain relief | 1 assembly | design | partially ordered; two parts below | £3.40 listed parts; remaining TBD | Assemble and verify polarity; use existing USB-A to USB-C cable to avoid soldering the display |
| HW-006a | JST-PH 2-pin female connector lead, Pi Hut 102818 | 1 | prototype selection | ordered from Pi Hut, user confirmed 2026-09-22 | £0.80 incl VAT | Charger LOAD output to converter input; verify polarity |
| HW-006b | USB-A female breakout — horizontal, Pi Hut 106576 | 1 | prototype selection | ordered from Pi Hut, user confirmed 2026-09-22 | £2.60 incl VAT | Converter output to existing display USB cable |
| HW-007 | Accessible charging inlet: existing USB-C port initially; extension or dock conditional | 0 or 1 extra inlet | design | not ordered | TBD if needed | Resolve port access without compromising enclosure or serviceability |
| HW-008 | Service power isolation for external base pack; exact switch TBD | 0 or 1 | research | not ordered | TBD if needed | Do not assume Waveshare battery switch isolates external 5 V; verify coverage and accessibility |
| HW-009 | External wake device or low-power latch, only if touch wake cannot meet energy target | 0 or 1 | optional | not ordered | TBD if needed | Validate native touch wake before adding hardware; preserve touch-wake requirement |
| HW-010 | Custom printed upper housing / bezel | 1 | design | not ordered | TBD | Fit print after display measurements; choose material/finish |
| HW-011 | Custom printed base / removable underside | 1 assembly | design | not ordered | TBD | Size around selected pack, charge electronics and antenna clearance |
| HW-012 | Battery cradle, cushioning and electrical insulation | 1 assembly | design | not ordered | TBD | Prevent pack movement and compression; retain service access |
| HW-013 | Screws, inserts and board standoffs | TBD set | design | not ordered | TBD | Derive exact counts and sizes from mounting design |
| HW-014 | Non-slip silicone feet or base pad | 1 set | design | not ordered | TBD | Compare grip/stability, adhesive and removable-pad options |
| HW-015 | Protective perimeter gasket / glass support | 1 set if needed | design | not ordered | TBD | Prevent point loads; avoid unnecessary touch overlay |
| HW-016 | Additional base ballast | 0 or 1 | optional | not ordered | TBD if needed | Decide after battery mass and tilt-stability evaluation |
| HW-017 | Existing user-owned USB-C power supply and suitable cable | 1 supply | reuse existing | owned / fulfilled, user confirmed 2026-09-22 | £0 incremental | Use normal 5 V USB output into BQ24074 USB-C input; no Raspberry Pi PSU purchase needed. Exact owned model and bench behaviour not yet recorded |
| HW-018 | Charging dock and contact pair | 0 | excluded from current design | not applicable — excluded | N/A | Stationary River Stone uses a rear charging inlet proposal; no controller-to-base transfer |

## Existing system and included functions

| ID | Item | Status / cost treatment |
| --- | --- | --- |
| SYS-001 | Naim NDX 2 | Existing; outside controller BOM cost |
| SYS-002 | Existing Naim amplifier and System Automation connection | Wired down/up verified (D011); preserve connection. Exact model/cable inventory is separate; no new cable needed by this plan |
| SYS-003 | Existing Home Assistant Pi | Available optional command/metadata bridge; outside base battery and new-parts subtotal |
| INC-001 | ESP32-S3, Wi-Fi/BLE, touch controller and LCD interface | Included in HW-001; no separate MCU/Wi-Fi/touch board |
| INC-002 | microSD slot and onboard RTC | Included in HW-001; card and RTC backup cell not selected; add only if justified |
| EXC-001 | Speaker, DAC, audio amplifier and audio relay hardware | Excluded: NDX 2 performs native audio playback |

## Bench equipment — separate from installed BOM

| Item | Quantity | Status | Purpose |
| --- | --- | --- | --- |
| USB data cable and suitable 5 V source | 1 each | cable and USB-C PSU owned, HW-017 | Firmware and first powered tests |
| Current profiler / meter with suitable sleep-current range and peak capture | 1 | user reports tools owned; record model/range at test | Measure standby and wake energy; basic USB meter alone may miss microamp sleep or short peaks |
| Multimeter | 1 | owned, user confirmed | Polarity, voltage and continuity |
| Caliper | 1 | inventory unverified | Mounting, connectors and enclosure fit |
| Temperature probe | 1 | inventory unverified | Charging/enclosure thermal measurements |
| Bambu Lab P1S, 0.4 mm nozzle | 1 existing | user-confirmed home printer | Fit and finish prototypes; filament selection remains open |

## Cost accounting

Current order references: Pi Hut £34.10 plus the unrecorded display price and delivery; SK Pang sniffer £8.52 before unrecorded delivery; Pimoroni checkout £42.89 including shipping and estimated tax. These are not a verified final paid total. PSU is already owned (£0 incremental).

The following USD scenario is retained only as historical research and must not be used as the current order total:

Selected display reference subtotal: **USD 36.99 for HW-001 only**, quoted 20 September 2026. This is not a refreshed price or total build cost.
External-route candidate prices: HW-002 Adafruit 353 USD 24.50; HW-003 Adafruit 4755 USD 14.95, checked 2026-09-20, shipping/tax excluded. These are unselected alternatives within their functional rows, not extra parts. The historical scenario did not include a converter price; the ordered U3V40F5 is now listed above at £9.60. Screen + these two candidates = USD 76.44, an incomplete scenario subtotal excluding converter, monitoring, harness, enclosure and charging supply. See [power review](power-review.md) for limits.

All remaining costs are unknown or conditional. No GBP conversion, stock guarantee, shipping or tax estimate has been assumed.
Keep original quote currency. If a converted budget is added, record exchange rate and date.
Add exact supplier, part/revision, quantity, quote date, paid cost and procurement state to each row as selection progresses.
Do not sum alternative power routes or count included functions twice.

## Historical procurement research — 21 September (superseded by current status)

[Consolidated UK shopping list](prototype-shopping-list.md) covers all functional rows and assembly consumables. BAT0008 6600 mAh (£15 listed) is a UK battery candidate; confirm variant availability, polarity and fit. BQ24074 (£14.40) remains an external charger candidate. Smaller U3V16F5 (£6.70, sold out) is an alternative converter for load testing, not a selected replacement for U3V70F5. Do not sum alternative converters. Combined BQ25185/boost board rejected for this basket because fixed six-hour charging timeout is a poor match for the large pack. No power route is released or runtime validated.

Microphone + sniffer new-purchase subtotal is £15.22 before delivery and screen; display/charger PSU is now owned (£0 incremental), superseding the previous £22.92 subtotal. Historic USD figures above remain historical; no complete build price is claimed.

## Larger battery follow-up — 22 September

[Review](larger-battery-review.md) promotes BAT0014 10,050 mAh as the leading candidate: 69.5 x 57 x 20.5 mm maximum body within the 80 x 64 x 26 mm reservation, 37.185 Wh nominal. BAT0015 13,400 mAh requires layout revision. Published Adafruit BQ24074 schematic grounds TMR (safety timers disabled), resolving the earlier timer-configuration research item for that source revision. Delivered hardware, charging and runtime remain untested.

## Pi Hut order — 22 September

User confirmed all six items above ordered. Recorded basket subtotal is £34.10 plus the display and delivery; display paid price, final invoice total and arrival date are not supplied. Prices remain basket references, not invoice verification. Earlier converter comparisons and cost scenarios are historical; U3V40F5 is the ordered prototype converter. Procurement does not establish validated integration or battery life.

## Battery order — 22 September

User confirmed Pimoroni BAT0014 10,050 mAh ordered. Checkout screenshot showed £42.89 including shipping and estimated tax; no discount acceptance or final invoice supplied. Delivery not yet confirmed. All eight named prototype electronics/connector items across Pi Hut, SK Pang and Pimoroni are now ordered; PSU, tools and wires are owned. Remaining monitoring, temperature sensing and enclosure assembly details are still open.

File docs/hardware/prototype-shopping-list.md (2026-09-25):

# Prototype procurement BOM — UK

> **D030 update — 25 September 2026:** active hardware is iPhone 11 + selected UGREEN Nexode 20000mAh PD 20W QC Power Bank. See [current mounting and power packaging](river-stone/iphone-mount/README.md). Waveshare-specific parts, experiments and purchase recommendations below are fallback history; actual prior order records remain valid. This update does not cancel orders or authorize more purchases.
Updated 22 September 2026. Covers one controller and bench bring-up. All eight named prototype parts are ordered: six from Pi Hut, one microSD sniffer from SK Pang, and one BAT0014 battery from Pimoroni. User confirmed 22 September; receipt/delivery not yet confirmed.

User inventory: tools and wires already owned, including the supplies/meters asked about; USB-C power supplies already owned (user confirmed 22 September; HW-017 fulfilled, no purchase needed). Screen became available and is included in the confirmed Pi Hut order. Exact meter capability should still be recorded with measurements.

## Supplier orders and outstanding purchases

Prices are listed GBP item prices checked 21 September, excluding delivery. Pi Hut prices include VAT. Pimoroni BAT0014 checkout screenshot showed £25 subtotal, £10.74 shipping and £7.15 estimated tax (£42.89 total); final paid amount and discount acceptance are unconfirmed. Stock can change. A listing with an Add to cart button alone is not proof of stock.

| BOM | Part / supplier link | Qty | Unit price | Stock / purchasing status |
| --- | --- | --- | --- | --- |
| HW-001 | [Pi Hut Waveshare display listing](https://thepihut.com/products/esp32-s3-development-board-with-4-3-capacitive-touch-lcd-display-800-x-480): **ESP32-S3-Touch-LCD-4.3B, without case, Waveshare 27848** | 1 | Exact bare-board quote pending | ordered from Pi Hut, user confirmed 2026-09-22; verify bare 4.3B revision on arrival |
| HW-020 | [Adafruit 3421 SPH0645LM4H I2S microphone — Pi Hut](https://thepihut.com/collections/audio/products/adafruit-i2s-mems-microphone-breakout-sph0645lm4h) | 1 | £6.70 | ordered from Pi Hut, user confirmed 2026-09-22; integration untested |
| HW-021 | [SparkFun microSD Sniffer — SK Pang](https://www.skpang.co.uk/products/microsd-sniffer), USD-SNIFFER / SparkFun TOL-09419 | 1 | £8.52 incl VAT | Ordered from SK Pang, user confirmed 2026-09-22; delivery not confirmed. Experimental microphone pin access, integration untested |
| HW-017 | Existing user-owned USB-C power supply | 1 owned; 0 to buy | £0 incremental | Fulfilled from existing stock, user confirmed 22 September. Use normal 5 V USB output with a suitable cable for the BQ24074 USB-C input |
| HW-002 | [Pimoroni BAT0014 10,050 mAh](https://shop.pimoroni.com/products/high-capacity-lithium-ion-battery-pack?variant=32012684623955), protected 3.7 V pack | 1 | £25.00 | Ordered from Pimoroni, user confirmed 2026-09-22. Body fits reserved envelope; confirm delivered pack polarity and cradle/lead routing |
| HW-003 | [Adafruit BQ24074 4755 charger — Pi Hut](https://thepihut.com/products/adafruit-universal-usb-dc-solar-lithium-ion-polymer-charger-bq24074) | 1 | £14.40 | ordered from Pi Hut, user confirmed 2026-09-22; external-power integration untested |
| HW-004 | [Pololu U3V40F5 — Pi Hut](https://thepihut.com/products/5v-step-up-voltage-regulator-u3v40f5), POL4012 | 1 | £9.60 | ordered from Pi Hut, user confirmed 2026-09-22; load and standby testing pending |
| HW-006a | [JST-PH 2-pin female connector lead — Pi Hut](https://thepihut.com/products/jst-ph-2-pin-cable-female-connector-150mm), 102818 | 1 | £0.80 | ordered from Pi Hut, user confirmed 2026-09-22; charger LOAD-to-converter lead |
| HW-006b | [USB-A female breakout — horizontal — Pi Hut](https://thepihut.com/products/usb-a-breakout-horizontal), 106576 | 1 | £2.60 | ordered from Pi Hut, user confirmed 2026-09-22; converter-to-display USB connection |
| HW-022 | 10 kΩ NTC battery-temperature probe suitable for BQ24074 | 1 conditional | Unquoted | Part curve and attachment to pack still to specify; not a generic interchangeable thermistor purchase |

**Pi Hut order: six items, £34.10 plus screen price and delivery**, using recorded basket prices including VAT. Screen paid price and final invoice total are not supplied. PSU already owned (£0 new spend). MicroSD sniffer is ordered from SK Pang (user confirmed 22 September; £8.52 reference price, final invoice/delivery not supplied). Pimoroni BAT0014 battery is also ordered, user confirmed 22 September; checkout total £42.89, final paid amount unconfirmed. No delivery or integration test is recorded.

## Full remaining assembly coverage

Owned wires/tools are not automatic proof that all specialised connectors and mechanical stock are owned.

| BOM | Quantity / specification for prototype | Procurement treatment |
| --- | --- | --- |
| HW-005 battery monitoring | 0 boards initially for USB bench trial; 1 function required for battery build | Select accessible battery sensing/fuel gauge and low-voltage cutoff; do not assume Waveshare monitors an external pack |
| HW-006 harness | 1 assembly: pack-to-charger mating connector, charger OUT-to-converter, converter-to-display USB power cable; 5 mic signal/power wires plus channel-select strap | JST-PH female lead and USB-A female breakout ordered; reuse owned wire and USB-A to USB-C cable. Check polarity and cable gauge against measured peaks. Short soldered I2S leads preferred. Final connectors/cable lengths pending |
| HW-007 charge inlet | 0 extension on open bench; 1 accessible rear inlet in housing | First use charger's own USB port. Select extension type/length only after charger and enclosure fit; display USB and charger USB are different power paths |
| HW-008 service isolation | 0 extra on bench when unplugging pack; 1 disconnect function in finished build | Keyed battery connector can provide service isolation with underside removed. If adding external switch, rate for DC startup current and account for USB power too |
| HW-009 wake circuit | 0 initially | Buy only if measured native touch wake cannot meet requirement |
| HW-010/011 housing/base | 1 printed shell, 1 matching removable cover; 2 printed screen retainers | P1S already owned. Use matching v3 files; full build remains unreleased |
| HW-012 battery restraint | 1 printed cradle, 1 insulating liner, 1 retention strap/cushioning set | Dimensions depend on actual pack; avoid crushing cells or covering antenna |
| HW-013 fasteners | 4 provisional M3 screen-retainer screws + 4 M3 nuts; 4 cover screws; electronics standoffs/fasteners additional | Nut-pocket approach in current CAD, not heat-set inserts. Exact lengths, cover thread treatment and board fasteners need fit coupon/actual board; no final fastener kit specified |
| HW-014 feet | 4 non-slip silicone feet or 1 cut base pad | Select thickness after base stability check; same-supplier consumable if available |
| HW-015 glass support | 2 compliant strips at retainer contacts; provisional 0.8 mm material | CAD assumes 0.2 mm compression; stiffness/load not validated. No pad over active display or touch surface |
| HW-016 ballast | 0 initially | Battery adds mass; decide after tilt test |
| HW-017 charging cable | Reuse existing suitable USB cable for owned PSU | BQ24074 has USB-C input; no separate Raspberry Pi PSU purchase. Confirm cable availability during assembly |
| HW-020 mic mounting | 1 small printed mount + compliant support; 1 acoustic opening | Keep bottom acoustic port unobstructed. Locate away from touch vibration and converter; no membrane/mesh selected yet |
| HW-021 sniffer restraint | 1 insulating support/strain relief | Exposed contacts and card overhang require fit check; no SD card inserted during mic use |
| HW-022 temperature sensing | 1 external probe if external charging route retained | Sensor for charging control differs from owned bench temperature measurement; confirm part and thermal contact |
| Filament / finish | Approximately one prototype's material, plus coupons/reprints | Existing filament inventory unspecified; no full new spool assumed. Slicer study does not cover a released complete assembly |
| Bench tools/wire/meters | Existing; £0 new acquisition allowance | User-confirmed. USB-C PSU also owned. Record meter model/range when running tests |
| HW-018/019, EXC-001 | 0 dock, phone, speaker, DAC or amplifier | Excluded; native NDX 2 playback |
| SYS-001/002/003, INC-001/002 | Existing Naim system/Pi and included display MCU/radio/touch/RTC | No duplicate purchases; microSD card and RTC cell not required for first trial |

## Purchase readiness and power findings

The eight prototype parts have been ordered for evaluation. Pin access, charge duration, load peaks, cutoff and mechanical fit remain untested. Monitoring, temperature sensing and final enclosure fittings still need resolution; the finished-build BOM is not yet complete.

The [Pimoroni-linked BAT0008 datasheet](https://cdn.shopify.com/s/files/1/0174/1800/files/PKcell_ICR18650_6600mAh_Final.pdf) specifies 3.7 V nominal, 4.2 V charging, 3.0 V discharge endpoint and 3 A maximum continuous charge/discharge. This supports further evaluation with a 1 A charger; it does not establish connector polarity or fit in the existing Adafruit-353-derived CAD reservation.

[BQ24074 documentation](https://learn.adafruit.com/adafruit-bq24074-universal-usb-dc-solar-charger-breakout/pinouts) distinguishes its approximately 3–4.4 V load output from regulated 5 V. A boost converter is required for this route. Verify charge safety-timer configuration against the large pack, charge termination during use, thermal performance and low-voltage shutdown before integration. Keep the Waveshare battery socket empty on this external route. Avoid simultaneously feeding external 5 V and a programming host until backfeed paths are checked.

Historical comparison (superseded for procurement by ordered U3V40F5): [Pololu U3V16F5](https://www.pololu.com/product/4941) is a smaller locally listed candidate, not a selected replacement for U3V70F5: its 1.6 A figure is input current, not 5 V output current. It has no true output disconnect and needs system-level low-battery control. Startup, full-brightness/Wi-Fi peaks and idle losses determine suitability.

The [Adafruit 6106 BQ25185 combined 5 V board](https://learn.adafruit.com/adafruit-bq25185-usb-dc-solar-charger-with-5v-boost-board/overview) was examined but is not recommended for this basket. Its fixed six-hour charge timeout can interrupt a depleted 6600 mAh pack's charge; the guide also flags startup difficulty with immediate loads above 200 mA. Its £8.60 price and reduced board count do not resolve these requirements.

After the Pi Hut order: record display paid price and final invoice, check delivered board revisions, sniffer fit/net continuity, battery dimensions/polarity and exact mechanical consumables. Battery and sniffer are ordered; delivery and integration checks are pending. No runtime or weeks-standby claim has been validated.

## Larger pack update — 22 September

See [larger battery review](larger-battery-review.md). BAT0014 replaces BAT0008 and is ordered as the prototype battery, user confirmed 22 September. BAT0008 discussion above is historical comparison. BAT0014 body is 69.5 x 57 x 20.5 mm maximum, nominal energy +52.3%. The published Adafruit BQ24074 netlist grounds TMR, so its charge safety timers are disabled; check the delivered revision, thermal behaviour and charge termination. The earlier request to establish source timer configuration is now answered, not a claim of a tested charging system.

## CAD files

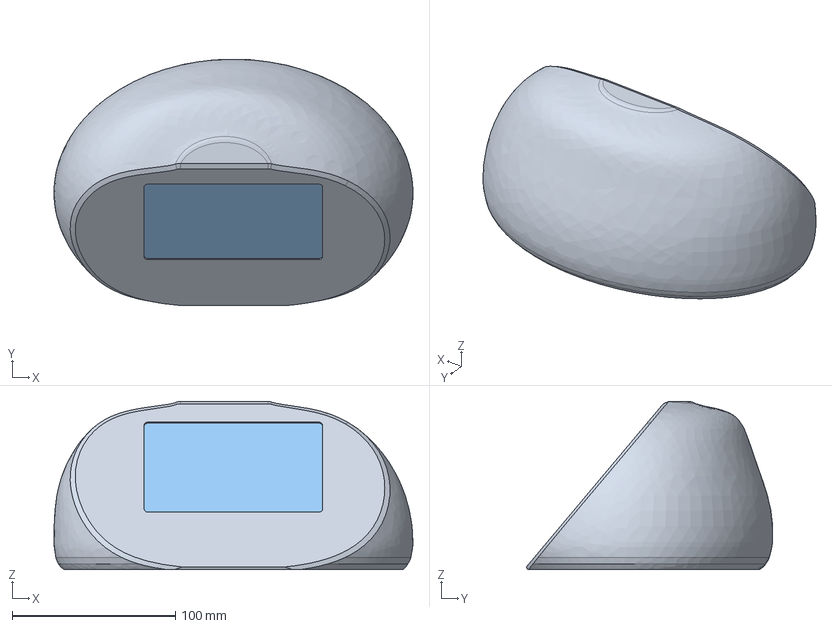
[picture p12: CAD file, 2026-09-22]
docs/hardware/river-stone/shell-v3/assembly-envelopes.step
220.1 x 151.1 x 103.0 mm

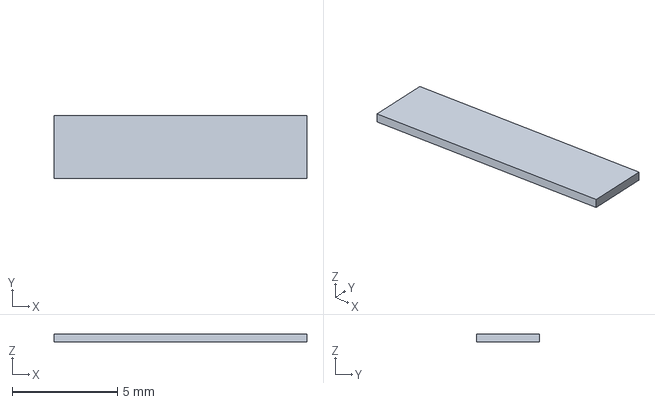
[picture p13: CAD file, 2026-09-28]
docs/hardware/river-stone/iphone-mount/sample-v2/spacer-0.4mm.step
12.0 x 3.00 x 0.4 mm

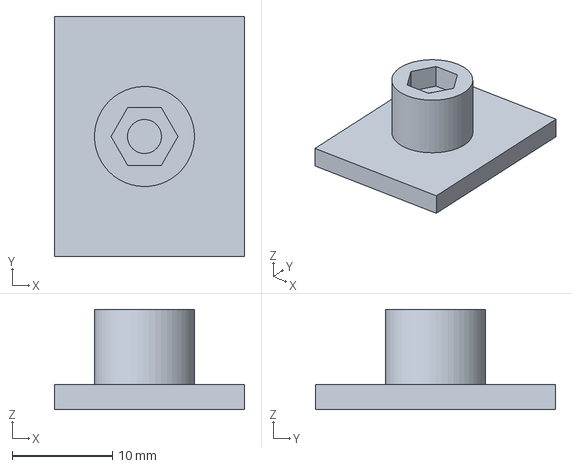
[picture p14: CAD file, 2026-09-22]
docs/hardware/river-stone/shell-v3/retainer-mount-coupon.step
19.0 x 24.0 x 10.00 mm

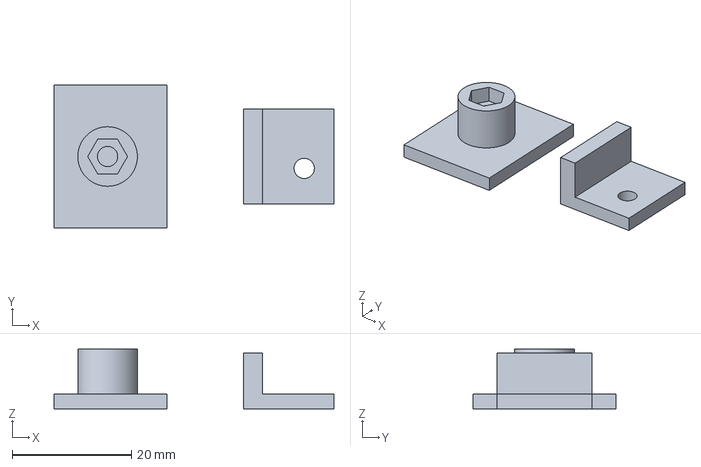
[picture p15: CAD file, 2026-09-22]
docs/hardware/river-stone/slice-v1/fit-coupons.3mf
47.0 x 24.0 x 10.0 mm

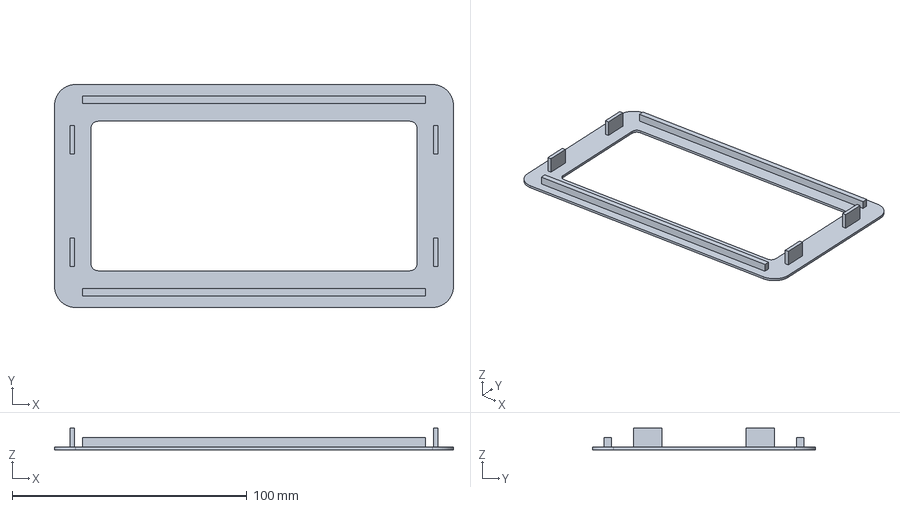
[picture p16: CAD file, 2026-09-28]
docs/hardware/river-stone/iphone-mount/sample-v2/aperture-frame.step
170.0 x 95.0 x 9.20 mm

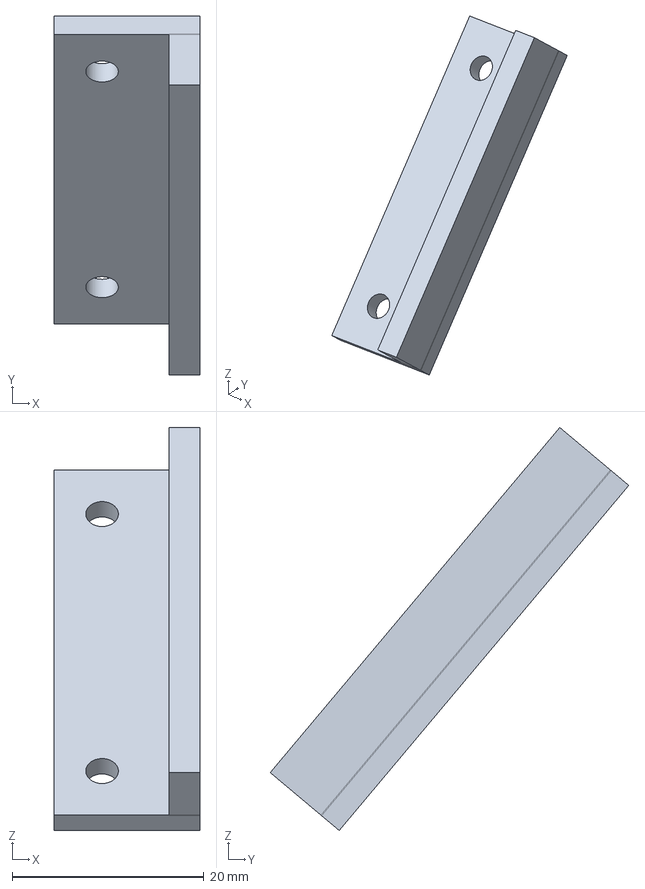
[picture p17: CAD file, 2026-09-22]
docs/hardware/river-stone/shell-v3/retainer-left.step
15.2 x 37.4 x 42.0 mm

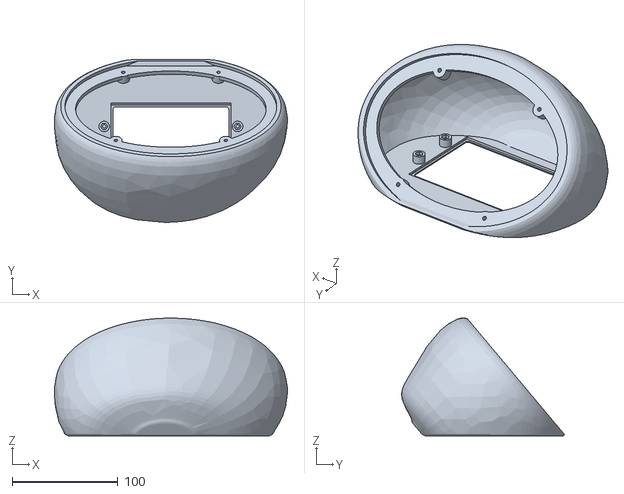
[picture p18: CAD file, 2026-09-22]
docs/hardware/river-stone/slice-v1/shell-facet-down.stl
220.1 x 153.7 x 111.3

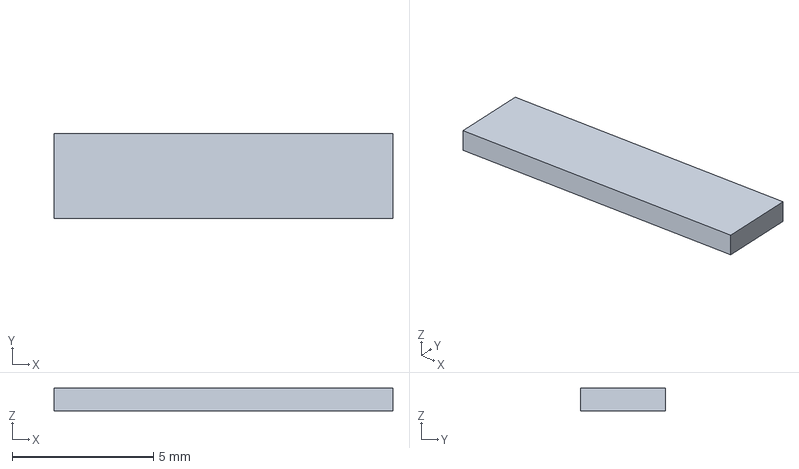
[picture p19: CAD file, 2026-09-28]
docs/hardware/river-stone/iphone-mount/sample-v2/spacer-0.8mm.step
12.0 x 3.00 x 0.8 mm

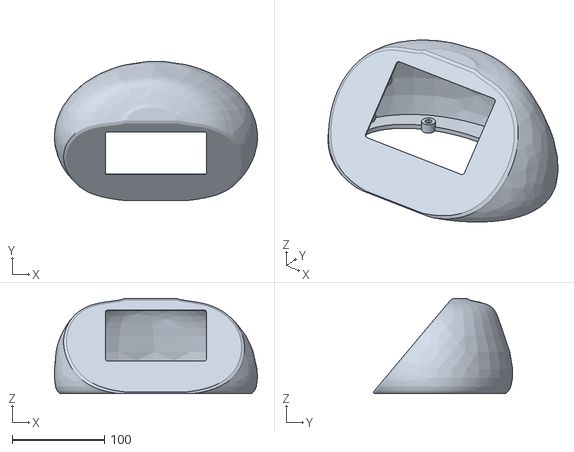
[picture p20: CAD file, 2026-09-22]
docs/hardware/river-stone/slice-v1/shell-underside-down.stl
220.1 x 151.1 x 103.0

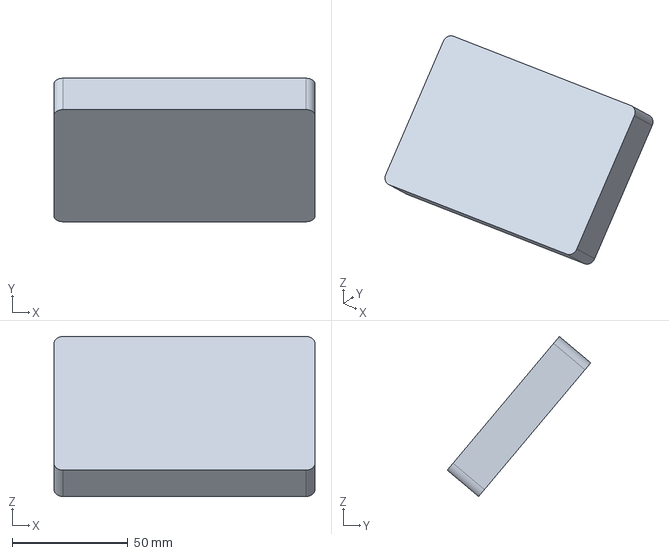
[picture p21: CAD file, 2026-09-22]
docs/hardware/river-stone/shell-v3/module-envelope.step
112.6 x 62.0 x 69.1 mm

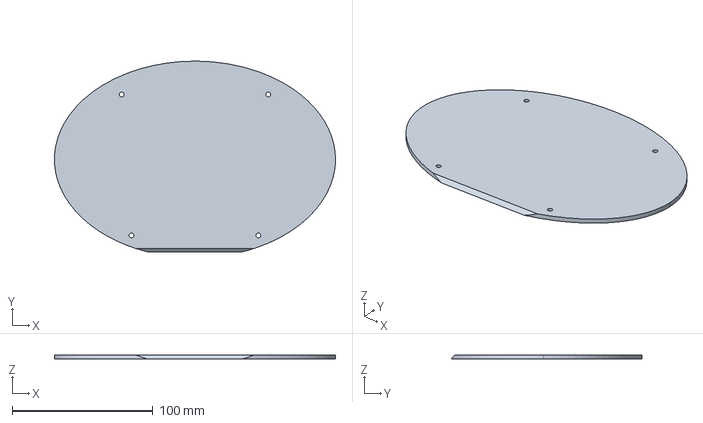
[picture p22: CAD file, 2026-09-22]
docs/hardware/river-stone/shell-v3/cover-study.step
199.3 x 135.4 x 3.00 mm

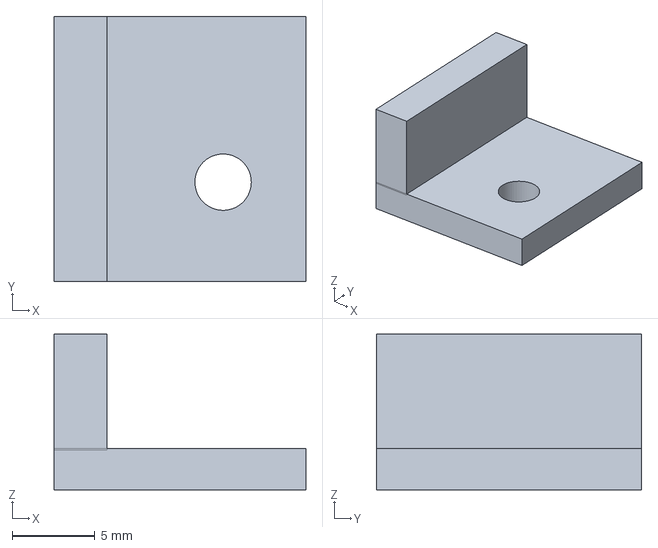
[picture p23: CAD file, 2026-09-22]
docs/hardware/river-stone/shell-v3/retainer-strip-coupon.step
15.2 x 16.0 x 9.40 mm

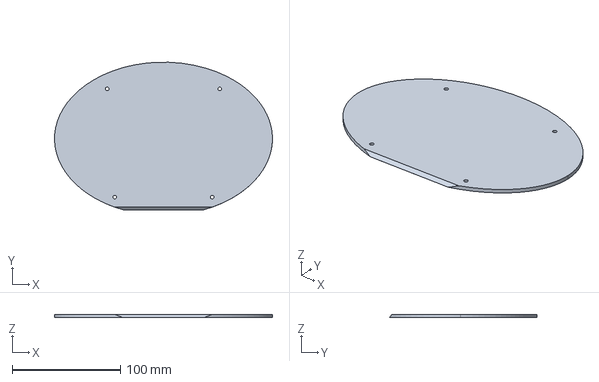
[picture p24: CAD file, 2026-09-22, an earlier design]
docs/hardware/river-stone/shell-v1/cover-study.step
201.4 x 136.3 x 3.00 mm

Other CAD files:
docs/hardware/river-stone/shell-v3/retainer-right.step
docs/hardware/river-stone/shell-v3/shell-study.step
docs/hardware/river-stone/shell-v1/assembly-envelopes.step
docs/hardware/river-stone/shell-v2/assembly-envelopes.step
docs/hardware/river-stone/iphone-mount/sample-v1/spacer-0.8mm.step
docs/hardware/river-stone/iphone-mount/sample-v1/aperture-frame.step
docs/hardware/river-stone/iphone-mount/sample-v1/aperture-frame.stl
docs/hardware/river-stone/iphone-mount/sample-v1/spacer-0.4mm.step
docs/hardware/river-stone/iphone-mount/sample-v2/aperture-frame.stl
docs/hardware/river-stone/iphone-mount/sample-v2/spacer-0.4mm.stl
docs/hardware/river-stone/iphone-mount/sample-v2/spacer-0.8mm.stl
docs/hardware/river-stone/shell-v1/cover-study.stl
docs/hardware/river-stone/shell-v1/module-envelope.step
docs/hardware/river-stone/shell-v1/module-envelope.stl
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

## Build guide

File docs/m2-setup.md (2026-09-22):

# Host controller setup console - 22 September 2026

The operator-facing host flow now uses the [tested enrollment foundation](m2-provisioning.md). It performs local status, private pairing, read-only verification and explicitly confirmed local forgetting. The approved native UI and its labelled hardware setup simulations are unchanged.

## Run it

Use a private interactive terminal in the repository, with the existing installed Python dependencies. Close the desktop controller/helper first: setup uses the same exclusive protected-vault lock and never bypasses it. Obtain the intended bridge origin and trust file through an independently trusted local channel. Do not discover or accept trust from the pairing response.

Prepare or reuse the public desktop JSON used by `--bridge`. Setup requires absolute trust/state paths, accepts only `url`, `trust`, `state` and optional boolean `allow_live`, and limits the file to 16 KiB. Example placeholders below are not an installed configuration:

```json
{
  "url": "https://bridge.example:8991",
  "trust": "C:/private/ndx-controller/trust.pem",
  "state": "C:/private/ndx-controller/state"
}
```

This file contains no setup code, bearer credential or provider authorization. Setup does not generate certificates, download trust, write this configuration or enable live operation. Keep private addresses and configuration outside Git.

```text
python tools/m2_setup.py --config C:/private/ndx-controller/desktop.json status
python tools/m2_setup.py --config C:/private/ndx-controller/desktop.json pair
python tools/m2_setup.py --config C:/private/ndx-controller/desktop.json verify
python tools/m2_setup.py --config C:/private/ndx-controller/desktop.json forget
```

- **Status:** local enrollment state and controller ID only. It does not contact a bridge or require the trust file to exist. A saved pairing is not a connectivity claim.
- **Pair:** only available for an unpaired record. Displays the intended origin and trust-file SHA-256; compare these with the bridge administrator through a trusted channel. Type `PAIR`, then enter the locally issued single-use code at the hidden prompt. The code is never a command argument, echoed output or durable field. Redirected/noninteractive input is refused. If Python cannot disable echo and attempts a fallback, setup aborts. Existing, unknown or damaged enrollment is not overwritten. One pairing request is sent; verification is a separate explicit step.
- **Verify:** sends one authenticated snapshot request. Can run noninteractively; never sends play, volume, transport, library writes or voice commands. A connection failure preserves pairing; revocation records authorization-required state.
- **Forget:** shows local state and explains that forgetting does not revoke the bridge credential. Requires an interactive `FORGET`; any other answer cancels. It works without a trust file and changes only local controller/enrollment records. Revoke the identified device at the bridge first; resolve ambiguous orphan IDs locally. There is no automatic remote revoke or re-pair.

The bridge's local console provides `devices`, `pair`, `cancel` and `revoke DEVICE`. Do not put setup codes in shell commands, shared logs or screenshots. The setup console rejects unexpected arguments without echoing them and reports failures without raw exception/configuration output. Successful commands exit 0; cancellation/operational failure exits 1; invalid arguments exit 2.

If interrupted, run status before retrying. An interrupted remote pairing may already have issued a credential; the durable pending marker reports an unknown outcome. Follow the [local recovery procedure](m2-provisioning.md#recovery-procedure-and-design-boundary). Do not automatically repeat setup or erase the bridge's command history. Stop after a storage error and inspect/reopen protected storage. Trust replacement requires explicit authenticated migration planning; do not use local forgetting to bypass identity checks.

## Fresh evidence

- **107 Python tests passed**, including 14 setup-console cases for hidden input, cancellation, noninteractive rejection, existing records, unknown outcomes, sanitized failures, local forgetting/status, read-only verification, argument redaction, public-config validation and refusal of echo fallback.
- **`python tools/m2_setup_demo.py` passed** against an authenticated silent loopback TLS bridge and temporary protected vaults. Real CLI subprocesses exercise status/verify, including revoked authorization. The console's pair/forget paths use injected synthetic terminal input, enroll once, cancel forgetting, recover without a trust file and explicitly re-pair. No setup code or issued credential appeared in captured output. The silent Naim adapter recorded zero playback/volume calls.
- **`python tools/m2_provisioning_demo.py` passed** after allowing local-only enrollment inspection/recovery without trust. Durable pairing, bound helper compatibility and old-credential rejection remain tested.

The hidden-entry test uses injected input; physical terminal echo suppression remains a manual host check. No actual user credentials or private configuration were accessed. No C/LVGL/ESP32 source or approved UI change occurred; native builds, screenshots and previous broader native smoke results remain prior evidence and were not rerun for this console-only slice. No hardware installation, flashing, efuse, Pi deployment or live Naim/provider operation occurred. HP-01 and physical P3/P4/P5 remain open.

Next: validate private prompt behavior on the intended host terminal with synthetic setup first. When NDX network access returns, use separately scoped read-only metadata/artwork/reconnect validation. Production certificate renewal/rotation, installation packaging and physical ESP32 provisioning remain separate work.

## Trust-update follow-up

The console now also supports `trust-update` with the proposed public configuration. It requires interactive `UPDATE TRUST`, independent comparison of old/new fingerprints and a successful snapshot before committing the new same-origin binding. `status` now shows the saved fingerprint, including without a trust file. See [procedure and interruption evidence](m2-trust.md). Earlier command counts/next-work statements above describe the setup checkpoint.

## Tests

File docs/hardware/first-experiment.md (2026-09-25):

# HP-01 — USB-powered display, touch wake and energy baseline

> **D030 update — 25 September 2026:** active hardware is iPhone 11 + selected UGREEN Nexode 20000mAh PD 20W QC Power Bank. See [current mounting and power packaging](river-stone/iphone-mount/README.md). Waveshare-specific parts, experiments and purchase recommendations below are fallback history; actual prior order records remain valid. This update does not cancel orders or authorize more purchases.

Status: ready-to-execute protocol, not executed. [Native fixture build recipe and diagnostic hooks](../../firmware/README.md) are prepared; compilation and hardware trials remain open. 20 September 2026. No procurement recorded. Dependencies: HW-001 exact model available, measurement equipment inventoried, revision-matched schematic and example reviewed.

## Question and setup

Can the preferred Waveshare ESP32-S3-Touch-LCD-4.3B without case render the core 800 × 480 interaction, wake reliably from touch, and reach a standby load worth pursuing with a base battery?

Start with board only, a known suitable regulated USB 5 V source and data cable. Leave the battery socket and DC input unused. Use one verified supply path; disconnect programming-host power for standalone measurements unless isolation is established. Do not attach a battery, external charger or boost for this experiment.

Record exact SKU/revision, matching schematic/example source revision, firmware commit, SDK version/configuration, brightness settings and measured input voltage. Check touch IRQ routing, wake capability, polarity, pull state, touch supply/reset and backlight control against the actual revision. The existing GPIO4 wake inference is a hypothesis. Measure lens/board outline, mounting, depth and connector protrusions separately; do not mistake glass dimensions for board dimensions.

Use a profiler/shunt setup resolving the expected low standby range and capturing startup/Wi-Fi peaks without introducing enough voltage drop to brown out the board. Record instrument accuracy, range, sample rate and burden voltage. A coarse USB meter may establish active consumption but cannot pass the sleep/peak gate. Use a multimeter for supply checks. Keep fixture on an insulating stable support.

## Minimal firmware scope

Pin the vendor example/toolchain and prove its display/touch demo first. Add a fixture-only 800 × 480 screen with artwork, scrolling rows, keyboard and touch coordinates; no live Naim commands. Add timestamped state markers and configurable active, backlight-off, light-sleep and deep-sleep trials. Retain touch power and configure the verified external interrupt wake source. Start with backlight off before deeper sleep so each reduction is separately observable.

After wake, consume the wake contact and wait for release before accepting actions. Reinitialize touch/display/network, fetch a fixture snapshot and label it fresh. Ensure a held finger does not cause immediate sleep/wake cycling. Serial logging/programming hardware may alter current: record this and repeat steady-state tests detached. A stock example demo alone does not pass the fixture or sleep gate.

## Run sheet

| Step | Procedure / sample | Record / gate |
| --- | --- | --- |
| 1 | Boot stock demo; inspect at actual table angle and low/medium/high brightness | No display faults; actual touch edge coverage and viewing legibility. Failure isolates board/example first |
| 2 | Run core UI fixture, keyboard and scrolling for 10 min | Dropped touches, frame latency, free/peak heap/PSRAM, resets; no memory exhaustion |
| 3 | Measure boot/reconnect peaks, 5 min browsing per brightness level and 10 min connected idle | Average W, peak current/voltage droop, integrated Wh; avoid treating current at 5 V as battery-side current |
| 4 | Measure backlight-off awake, lowest workable light sleep and deep sleep for at least 10 min each | Touch retained? Average W, IRQ state, spontaneous wakes, wake energy; mark unsupported states failed, not zero draw |
| 5 | 100 deliberate sleep/wake cycles spanning centre/edges; include 10 held-contact cases | Proposed gate: 100/100 intentional wakes, zero unintended fixture commands, no wake loop/reset; provisional p95 visible feedback ≤1 s and fresh fixture state ≤5 s on healthy LAN |
| 6 | At least 8 h untouched standby then touch; repeat with Wi-Fi unavailable then restored | Spontaneous wake count and energy, successful wake; honest stale/offline state, automatic fresh-state recovery and no queued command replay |

Latency thresholds are initial engineering targets, not agreed user requirements. A fixture network result is not Naim recovery proof. Keep live integration under P2 and announce audible tests separately.

## Decision and energy interpretation

Report each state rather than quoting MCU deep-sleep specifications. Select the lowest measured state that preserves repeatable touch wake. A failure leads to targeted touch/schematic/firmware diagnosis or comparison with light sleep; do not silently replace touch wake with a button.

Compare USB standby power with the existing [power-review budgets](power-review.md). For example, the illustrative 10 Ah / 28-day / 15-minutes-active scenario allows about 20.8 mW standby under its assumptions. Exceeding that at the display input already makes that scenario infeasible; passing does not establish feasibility because the external power chain and wake load remain unmeasured. Final P4 calculations use battery-side energy and avoid double-counting converter losses.

Exit artifact: sanitized report with measured values/uncertainties and per-step pass/fail, firmware/build recipe, raw capture locations under ignored `local/`, and recommendation: retain display for next trial, diagnose a named fault, or escalate a requirement tradeoff. Update evidence/BOM only with observations. No weeks-of-standby claim, battery selection or final enclosure dimensions follows from HP-01 alone.

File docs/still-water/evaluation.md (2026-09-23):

# Evaluation: prototype against goals and spec

23 September 2026. The prototype (`reference/still-water.html`) renders 22 states; every state was measured with an automated gate (`tools/still-water-gates.py` in this package) and inspected by eye. Renders are in `reference/`. This evaluates the design, not any build, hardware or power claim.

## Goals

| Goal | How it is met | Evidence | Verdict |
|---|---|---|---|
| A beautiful coffee-table object first | At rest the panel is off and the dark inlay is the object; nothing on screen resembles a phone or a tablet app | `01-sleep`, hero scene | Pass on paper; the physical inlay coupon and the on-table trial decide |
| Intriguing at rest | The music's own colour fills the inlay; no chrome, one hairline; Presence remains an option, not a dependency | `05-still`, `02-presence` | Pass for Still; Presence stays gated on power |
| Highly functional | Every action from the approved interaction design is reachable within one touch of Still: transport, amplifier, Up next, Ask, Find, Library; Settings by long-press | `06-touched` | Pass; Settings entry needs the physical trial |
| Music first, not a terminal | Title is the only sofa-readable element; status is typeset into the composition, never a bar or a badge | all NOW states | Pass |
| Honest states | Offline, pending, unknown, stopped, missing artwork each have a distinct render with no fabricated content and no spinner | `11` to `16` | Pass |
| Native Naim path, no automatic playback | Ask produces a search; results require a tap; Play is the only filled control | `08-ask`, `09-three`, `19-detail` | Pass by construction; enforced by the unchanged bridge |
| First touch never acts | Sleep and Presence taps go to Waking, not to a control | prototype logic | Pass |
| Volume remains bounded and unresolved | Amplifier is a separate pill with busy and unknown states; no slider, no hold | `13-pending`, `14-unknown` | Pass |

## Automated gate, all 22 states

| Check | Rule | Result |
|---|---|---|
| Tap targets | 72 × 64 minimum; pills and filter words 96 × 56; Play/Pause 80 × 80; Ask 72 × 72 | Pass after widening Find's search and mic buttons (64 → 72) and giving pills a 96 minimum |
| Overlaps | No two targets intersect | Pass |
| Text size | Nothing below 15 units | Pass after raising six labels (Amp, Up next, Plays in, Listening, Three for you, result kinds) from 10 to 13 up to 15 |
| Contrast | Ink @ 100% ≥ 7:1 and secondary ≥ 4.5:1 over the sampled field behind each title | Pass after raising secondary ink from 62% to 70% (measured 4.2:1 at 62% on sage) and keeping offline metadata at 70% rather than dimming it twice (2.9:1) |
| Clipping | No title overflows its box without the two-line ellipsis; list rows clip only inside their scroll container | Pass after adding the long-title step-down (56 → 44) |
| Canvas | No text outside 800 × 480 except inside a scroll container | Pass |
| Script errors | None | Pass |

## Eye review, findings acted on

- Long titles at serif-56 in a 384-unit column broke to about 12 characters a line and lost the title. Step-down added and specified.
- Touched: the Up next block and the elapsed time sit close at the foot. Kept; the iPhone window's extra width relieves it and P3 will judge it on the table.
- Pending: a hairline ring on Next reads correctly; the amplifier at 35% while busy reads as disabled, which is the intent.

## Still open, by design

| Item | Decided by |
|---|---|
| Seated readability of sans-18 and caps-15 at 600 to 800 mm | P3 on the table with the prototype on the phone |
| Touch accuracy through the inlay window edge | Physical coupon |
| Wake feel and latency | Gate 2 in `iphone-architecture.md` |
| Standby power on either platform | Gate 1 or HP-01 |
| Presence | Out of scope until a measured power budget exists |
| Results screen (`09-three`) | Future; needs explained suggestions from the bridge |

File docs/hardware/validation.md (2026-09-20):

# Power budget and hardware validation

No hardware measurements yet. All checks below are pending; software tests do not validate electronics.

## Energy model

Use Wh to compare packs and loads at different voltages:
- Nominal pack Wh = nominal voltage x Ah.
- Usable Wh = nominal Wh x usable-capacity fraction x conversion efficiency.
- Daily energy = active W x active hours + idle W x idle hours + standby W x standby hours + wake energy.
- Runtime days = usable Wh / daily energy.

Use measured battery-side energy where possible; if measured there, do not apply converter losses again.
Record battery-side and USB-side measurements distinctly. Include converter/charger quiescent draw, touch sensing, LEDs, radio, self-discharge and startup peaks as applicable.

## Illustrative sizing only

Assume a 3.7 V pack, combined usable-energy factor 80%, and 2.25 W active load (manufacturer's 5 V / 450 mA reference; not a tested application value).
For 28-day pure standby, with no active use:

| Nominal pack | Usable energy under assumption | Maximum average load for 28 days | Continuous active equivalent at 2.25 W |
| --- | --- | --- | --- |
| 5,000 mAh | 14.8 Wh | 22.0 mW | 6.6 h |
| 10,000 mAh | 29.6 Wh | 44.0 mW | 13.2 h |

At 30 minutes/day at 2.25 W, active use alone consumes 1.125 Wh/day. The 10 Ah scenario then provides at most 26.3 days even with zero standby/wake consumption. Four weeks is an illustrative scenario, not the agreed target. Large battery size cannot replace a usage profile or measurement.

Additional 6.6 Ah and active-use scenarios, touch pin mapping and external-route checks are recorded in the [power review](power-review.md).

## Bench sequence

1. **Identity and fit:** photograph/record SKU and PCB revision, verify display and connector dimensions, map schematic sources. Record public results here; private photos/receipts can remain in local/.
2. **USB-powered screen test:** verify colour/artwork, touch edges, keyboard, scrolling, repeated controls, low brightness, viewing angle and touch stability. No audible Naim tests run automatically.
3. **Power states:** measure boot peak, Wi-Fi reconnect, active browsing at several brightness levels, connected idle, backlight off, deep sleep with touch sensing, and storage off. Capture both steady current and wake energy.
4. **Wake:** repeat touch wake after short and overnight idle; confirm first touch behaviour, fresh now-playing retrieval, Wi-Fi outage recovery and no unintended playback action. Compare measured delay with agreed target.
5. **Power route:** select route only after revision-matched connector/polarity and charging-path checks. Test regulated voltage at startup and low battery, charger plug/unplug and concurrent use. Measure charge duration and component/pack temperature inside a representative housing.
6. **Battery:** verify pack spec, usable energy and low-voltage handling. Implement warning and controlled shutdown before protection cutoff. Test recharge recovery and absence of repeated brownout loops.
7. **Enclosure:** check screen support, strain relief, service access, battery restraint, antenna clearance, heat, grip and tilt stability. Only then fix BOM quantities and final CAD.
8. **Daily use:** log real active/idle time and consumption over a representative period; reconcile predicted and observed runtime.

Touch wake is not proven by a controller having an interrupt pin. It requires retained power, compatible interrupt routing and working firmware in the chosen sleep state.

## Measurement record template

| Date / tester | HW-001 revision | Firmware commit | Power route / pack | State / brightness / Wi-Fi | Measurement point / instrument | Duration | Average / peak / energy | Wake delay / result | Evidence |
| --- | --- | --- | --- | --- | --- | --- | --- | --- | --- |
| TBD | TBD | TBD | TBD | TBD | TBD | TBD | TBD | TBD | TBD |

Update [evidence](../evidence.md) only when tests establish or disprove a claim. Do not mark the hardware milestone complete from datasheets, purchase or a successful display demo alone.

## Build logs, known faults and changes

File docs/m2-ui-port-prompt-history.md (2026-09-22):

# Continuation prompt — approved UI implementation

Historical implementation prompt, retained for scope and constraints. The core port below is now implemented and validated: begin further work with [current parity and remaining gaps](m2-ui-parity.md), inspect Git status and continue from the current checkout. Do not repeat the port or assume the earlier uncommitted checkpoint is still current. Repository updates were subsequently authorized; live audio, flashing and deployment remain outside this prompt.

---

Continue the NDX2 Controller M2 work in `local/river-stone-repo` within the Naim NDX2 Controller workspace. Implement the approved UI in the shared C/LVGL layer, desktop first; do not stop at another plan or redesign the approved direction.

First inspect Git status. Preserve all modified and untracked M2 implementation and detailed-design files. Closeout was on main at fcf1406 with uncommitted deliverables. Never reset/clean the checkout or replace it with local/river-stone-shell-repo. Preserve software-feasibility-v1 as the behavioural reference.

Read AGENTS.md, README.md, docs/m2-closeout.md, docs/decisions.md, docs/milestone-handover.md, docs/detailed-design-plan.md, docs/architecture.md, docs/deployment-design.md, docs/interaction-design.md, docs/roadmap.md, docs/controller-contract-v1.md, docs/m2-software.md, docs/ui-review/README.md, docs/ui-review/approval.md, docs/ui-review/index.html, firmware/README.md and docs/hardware/first-experiment.md. Approval and the interactive source supersede older rough layouts and chronological review notes. Do not renumber historical decisions.

Inspect shared UI/state/protocol code, desktop/ESP32 transports, bridge adapters and tests. Make a concise parity inventory, then implement useful end-to-end slices. The browser design board is not firmware. Keep ESP32 native C/LVGL and existing pinned SDK dependencies; do not add a browser runtime. Extend bounded contracts/models only where necessary, preserving adapter semantics and the runnable feasibility demo.

Implement the approved 800 × 480 default: 240 px art left, all metadata/controls right, four bottom sections; five evenly spaced unboxed previous/play-pause/next/speaker-minus/speaker-plus controls. Keep bitrate beside source, separate timeline, track heart, title/artist/album detail links, quiet Back, no redundant section headers. Preserve query/filter/page/list position on Back. Artist follow/unfollow and status; album/track compact Library actions and saved/unsaved/unknown states. Search and microphone icons; Settings gear with Display/Connection/Device direction. Use labelled fixtures for unavailable hardware and unknown/unavailable values for absent real metadata, never fabricated live bitrate or battery.

Voice entry starts recording immediately; Stop & search, Restart and Cancel replace the old separate review step. Bound capture to 30 seconds without automatic submission; Cancel/Back/exit discard capture. Update native fixture smoke expectations accordingly. No physical microphone implementation until pins/hardware are selected. AI suggestions become searches, never automatic playback. Display brightness/timeout/Wi-Fi controls must distinguish fixtures from real capabilities.

Preserve native Naim TIDAL playback on the NDX 2, resolving catalogue candidates through native Naim browsing before playback. No audio relay or substitute protocol. D011 is exactly one press plus four held frames spaced 0.2 seconds, one bounded burst per tap, both volume controls busy through completion. No retry, continuous hold or numeric amplifier level. Never replay playback, queue, collection-write or volume commands. Duplicate IDs are suppressed; timed-out mutations remain outcome unknown until authoritative reconciliation. On wake/disconnect discard pending gestures/commands, preserve browsing context, disable unavailable mutations and fetch authoritative state; consume the wake contact and wait for release.

Keep authentication, provisioned TLS trust, protected persistence and atomic single-flight renewal intact. No unauthenticated LAN service, provider secrets in firmware, real credentials/captures/private addresses in Git, flashing or efuse operations. Development-host bridge remains supported; Pi installation is conditional on inventory. Do not perform audible/live mutations automatically. Missing hardware, Pi or live credentials does not block fixture work. Keep B01 deferred unless blocking and exclude queue/playlist editing and general feature parity.

Use existing local tool installations before downloading anything. From repo root run appropriate validation:

    python -m unittest discover -s tests -v
    node --test tests/test_navigation.cjs
    python tools/m2_demo.py
    python tools/build_m2.py desktop
    python tools/m2_native_demo.py
    python tools/build_m2.py esp32

Review design with `python tools/ui_design_review.py` at http://127.0.0.1:8766/; it may already be running. Firmware preparation output local/m2/esp32-compile-v2 already exists and refuses overwrite. The build runner updates its owned overlays. SDK v5.2 and build outputs are under the user profile .espressif; see firmware/README.md for pins and paths. Report unavailable tools honestly; do not weaken ACL or TLS checks for sandbox convenience.

Capture and inspect actual LVGL output at 800 × 480, exercise the vertical slice and navigation/state failure cases with silent fixtures, and add meaningful tests for changed behavior. Keep desktop tests, firmware compilation, live observations and physical evidence separate. Update repository parity/status/evidence docs with implemented behavior and remaining gaps. HP-01 and physical P3/P4/P5 remain open; retain the precise hardware-arrival checklist in docs/m2-software.md. Finish with implemented changes, actual validation results and remaining blockers.

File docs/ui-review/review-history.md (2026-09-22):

# Historical UI review notes — superseded proposals included

Archived at closeout on 22 September 2026. Read [approval.md](approval.md) for current decisions; this chronology is not an implementation specification.

# UI design review — approved baseline

**Approved by the user, 22 September 2026.** See [approval and final baseline](approval.md). The entries below are chronological review history; later refinements supersede earlier layouts. Firmware and physical acceptance remain pending.

## Styling revision 02

Settings added on 22 September: a top-bar gear opens Display, Connection and Device. Display previews brightness (30–100%), Sage/Sand/Slate palettes and screen-off preferences, persisted locally with review notes. Brightness is a browser-only visual approximation; timeout is stored without running a timer or pretending to implement hardware sleep. Connection provides synthetic Wi-Fi selection, pairing/revocation and bridge-account guidance; no passwords, real codes, credentials or network changes are involved. Device shows unavailable battery, fixture software and diagnostics, and a first-run Wi-Fi → pairing → Now Playing walkthrough. Settings are not a fifth primary tab. The Display layout, preference persistence and first-run transitions were checked in the browser.

22 September: Now Playing includes synthetic bitrate (`1,411 kbps`, explicitly fixture-labelled), a track-specific like/unlike heart, and album/artist navigation with Back. Track likes are independent of album saves; the unknown-membership preview disables the heart and marks it with `?`. Offline/uncertain states disable mutations. Album opens Mezzanine details; artist opens a separate Massive Attack album list. This remains a local UI simulation: production bitrate must come from observed player metadata and show unavailable rather than infer a value from format or quality labels. No provider collection writes are performed.

First expert styling pass, requested by the user. The board now uses a clearer title/artist/album hierarchy, a compact circular play/pause focus, consistent line icons, quieter navigation, and thumbnail-led result rows. Amplifier controls move below artwork, separate from the track transport. Input fields and selected states use consistent charcoal/sage contrast; surfaces, borders and corner radii are less prominent. The 800 × 480 canvas and both artwork/navigation alternatives remain available. This is a review-prototype change, not approved LVGL implementation. Existing review notes remain stored under the original browser storage key.

Draft, 21 September 2026. This is a reviewable proposal, not accepted product design or replacement firmware. It compares a labelled reconstruction of the documented concept with an actual M2 LVGL fixture capture, and supplies an interactive 800 × 480 proposal.

Run from the repository root:

```powershell
python tools/ui_design_review.py
```

Open `http://127.0.0.1:8766`. The server binds loopback and exposes only the board and the existing `local/m2/native-captures/01-now.bmp` fixture capture. No bridge, credentials, microphone or player is used. If the capture is absent, the comparison image is unavailable; the proposal still works. The source is `index.html` here; the existing browser prototype and shared firmware are unchanged.

## Review sequence

1. Compare the original direction and current fixture under **Compare the starting point**. The original panel is a reconstruction from `docs/design-concept.md`, `docs/interaction-design.md` and `ui/index.html`, not an original screenshot. The fixture panel is an actual capture.
2. Review **Now Playing** first. Compare 240 px and 190 px artwork, and four sections with Voice inside Find versus a fifth Voice tab. The recommendation is 240 px art and four sections, pending user preference.
3. Try Find → album → Back, then Play album → Now Playing. Tap the query for a provisional on-screen keyboard. Inspect Collection, read-only Queue and voice recording/review/cancel. All effects are local simulations; search content and recording time are illustrative fixtures, not real search/recording.
4. Switch state previews: offline, unknown command result, amplifier busy, missing artwork, long title, empty and sign-in required. Observe disabled mutations and explicit reconciliation rather than command replay.
5. Record notes or reply in the conversation with R01–R04 choices. Notes and the two visual options are remembered in browser storage when available; they are not sent to the assistant. Download provides a plain-text review record. Checkboxes are a temporary walkthrough aid, not persistent acceptance evidence.

## Decisions awaiting review

| ID | Proposal | Acceptance needed |
| --- | --- | --- |
| R01 | Prominent artwork, 240 px default; 190 px alternative | Balance between artwork and title space |
| R02 | Playing / Find / Collection / Queue; Speak inside Find | Voice discoverability versus a fifth navigation target |
| R03 | Transport beside track metadata; amplifier controls below artwork | Labels, hierarchy and comfortable placement |
| R04 | Distinct saved / unsaved / unknown with separate row action | Clarity and accidental-activation avoidance |

These are local review identifiers, not accepted architectural decision IDs. No new decision is accepted by generating this board. The palette remains charcoal/sage/sand. Abstract artwork is a locally drawn placeholder; real artwork layout and loading behaviour need implementation after approval.

## Completion criteria

Desktop design completion requires explicit agreement on the core screens, hierarchy, typography, spacing, navigation and alternate states, followed by implementing those approved layouts in shared LVGL and verifying task flows and captures. This board is the first review deliverable. Provider sign-in details, full result-type browsing, loading/empty/error transitions, icon treatment and actual artwork processing are not all implemented by this mockup.

Physical readability, touch targets, seated angle, keyboard accuracy, wake release, microphone and latency remain HP-01/P3 work. Desktop review can settle visual direction now but cannot close those gates. Do not add queue/playlist editing or treat AI suggestions as playback.

Artist/library parity: restored explicit Follow artist / Unfollow artist with Following / Not following status. Album details and track details use Add to library / Remove from library with separate membership status. The Now Playing title opens track details; its heart shares that track membership. Album row and detail actions share per-album fixture state, and saved albums appear in the album collection. Unknown album membership requires a status check before a write. Verified follow, album add and track add in the browser; all remain silent fixture actions.

Navigation/control refinement: Back is now unboxed text navigation; artist/album chevrons are removed while hover/focus and click targets remain. Album/track detail actions show + Library or checked Library, with explicit membership text and accessible add/remove labels; list rows share plus/check/question icons. Volume replaces the Amplifier label and uses paired rounded minus/plus controls without numeric level or repeat. The synthetic bitrate is now 20 px beneath progress (1,411 kbps), with unavailable state offline. Inspected Now Playing and album layouts and verified the library transition and Back.

Playback spacing review: bitrate moved from between timestamps to the source row at 18 px. Now Playing reserves separate metadata, timeline and 100 px transport bands; transport controls retain 72 px targets with 32 px gaps. Verified the rendered layout at the 800 x 480 design canvas. This supersedes the earlier bitrate placement below progress.

Latest layout refinement: remove duplicate top-strip titles for Find, Collection and Queue while retaining active bottom navigation. Move Volume and its paired controls into the right-hand playback band alongside transport, leaving the artwork column clear. Both volume controls still share the bounded-burst busy state. Browser review confirmed Now Playing composition and the simplified Find header.

Control consistency: playback and volume now use unboxed controls throughout. Removed the Play/Pause circle and volume capsule/divider, aligned their 72 px hit areas and kept subtle hover/pressed feedback plus keyboard focus outlines. No changes to command behaviour.

Volume refinement: removed the visible Volume label and replaced standalone minus/plus symbols with speaker-minus and speaker-plus icons. Accessible Volume down/up labels, 72 px targets and shared busy state are retained.

Voice flow update (user direction, 22 September): Find uses an accessible microphone icon. Entry starts the timed recording fixture immediately; Stop & search submits a synthetic transcript to search without playback, Restart discards the attempt and starts again, and Cancel/Back discards and restores the previous context. Recording stops at 30 seconds without automatic search; the user can then search, restart or cancel. This supersedes the review-board transcript-review step; physical capture and firmware integration remain pending. Verified immediate entry, Restart and Stop & search in the browser.

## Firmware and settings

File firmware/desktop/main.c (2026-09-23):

/* SDL desktop runs exactly the shared LVGL renderer and controller state. */
#define SDL_MAIN_HANDLED
#include <SDL.h>
#include "lvgl.h"
#include "ui.h"
#include "fixture.h"
#include "transport.h"
#include "preferences_store.h"
#include <stdio.h>
#include <string.h>
static SDL_Renderer *renderer;
static SDL_Texture *texture;
static uint32_t pixels[800*480];
static lv_color_t draw_buffer[800*40];
static bool down, smoke_press_pending;
static int px,py;
static uint64_t release_at, smoke_clock_offset;
static void tap(int x,int y) { px=x; py=y; down=true;
    /* Reserve the contact before the next LVGL timer pass can start a read. */
    controller_ui_touch(true); smoke_press_pending=true; release_at=0; }
static void capture(const char *directory,const char *name) {
    /* UI timers can update widgets after the display timer in the same pass. */
    lv_refr_now(NULL);
    char path[1024]; snprintf(path,sizeof(path),"%s/%s.bmp",directory,name);
    SDL_Surface *surface=SDL_CreateRGBSurfaceFrom(pixels,800,480,32,800*4,0x00ff0000,0x0000ff00,0x000000ff,0xff000000);
    if(surface) { SDL_SaveBMP(surface,path); SDL_FreeSurface(surface); }
}
static uint64_t now_ms(void) { return SDL_GetTicks64()+smoke_clock_offset; }
static void log_event(const char *event) { printf("%llu %s fixture=1\n",(unsigned long long)now_ms(),event); }
static void flush(lv_disp_drv_t *drv,const lv_area_t *area,lv_color_t *colors) {
    for(int y=area->y1;y<=area->y2;y++) for(int x=area->x1;x<=area->x2;x++) {
        uint32_t c=lv_color_to32(*colors++); if(x>=0&&x<800&&y>=0&&y<480) pixels[y*800+x]=c;
    }
    /* Present the completed frame once, not the entire texture for every
     * 40-line LVGL strip. This avoids redundant full-screen software copies. */
    if(lv_disp_flush_is_last(drv)) {
        SDL_UpdateTexture(texture,NULL,pixels,800*4); SDL_RenderCopy(renderer,texture,NULL,NULL); SDL_RenderPresent(renderer);
    }
    lv_disp_flush_ready(drv);
}
static void read_pointer(lv_indev_drv_t *drv,lv_indev_data_t *data) {
    (void)drv; data->point.x=px; data->point.y=py;
    if(down&&smoke_press_pending) {
        /* Hold one synthetic contact for 90 ms after the input driver observes
         * it, not from before a potentially expensive draw/timer pass. */
        release_at=SDL_GetTicks64()+smoke_clock_offset+90; smoke_press_pending=false;
    }
    data->state=down?LV_INDEV_STATE_PRESSED:LV_INDEV_STATE_RELEASED;
    if(!controller_ui_touch(down)) data->state=LV_INDEV_STATE_RELEASED;
}
/* Smoke checks locate widget types, independent of decorative child order. */
static lv_obj_t *find_widget(lv_obj_t *parent,const lv_obj_class_t *type) {
    if(lv_obj_check_type(parent,type)) return parent;
    for(unsigned i=0;i<lv_obj_get_child_cnt(parent);i++) {
        lv_obj_t *found=find_widget(lv_obj_get_child(parent,i),type); if(found) return found;
    }
    return NULL;
}
int main(int argc,char **argv) {
    const char *smoke=NULL,*python=NULL,*config=NULL,*preferences_path=NULL,*preferences_smoke=NULL;
    bool transport_smoke=false;
    for(int i=1;i<argc;i++) {
        if(!strcmp(argv[i],"--smoke")&&i+1<argc) smoke=argv[++i];
        else if(!strcmp(argv[i],"--bridge")&&i+2<argc) { python=argv[++i]; config=argv[++i]; }
        else if(!strcmp(argv[i],"--preferences")&&i+1<argc) preferences_path=argv[++i];
        else if(!strcmp(argv[i],"--preferences-smoke")&&i+1<argc) preferences_smoke=argv[++i];
        else if(!strcmp(argv[i],"--transport-smoke")) transport_smoke=true;
        else return 2;
    }
    SDL_SetMainReady();
    if(SDL_Init(SDL_INIT_VIDEO|SDL_INIT_TIMER)!=0) return 1;
    SDL_Window *window=SDL_CreateWindow("NDX2 SILENT FIXTURE",SDL_WINDOWPOS_CENTERED,SDL_WINDOWPOS_CENTERED,800,480,smoke?SDL_WINDOW_HIDDEN:0);
    renderer=SDL_CreateRenderer(window,-1,SDL_RENDERER_SOFTWARE);
    texture=SDL_CreateTexture(renderer,SDL_PIXELFORMAT_ARGB8888,SDL_TEXTUREACCESS_STREAMING,800,480);
    lv_init(); static lv_disp_draw_buf_t draw; lv_disp_draw_buf_init(&draw,draw_buffer,NULL,800*40);
    static lv_disp_drv_t display; lv_disp_drv_init(&display); display.hor_res=800; display.ver_res=480;
    display.draw_buf=&draw; display.flush_cb=flush; lv_disp_drv_register(&display);
    static lv_indev_drv_t input; lv_indev_drv_init(&input); input.type=LV_INDEV_TYPE_POINTER; input.read_cb=read_pointer; lv_indev_drv_register(&input);
    platform_t platform=fixture_platform(now_ms,log_event);
    if(python&&!desktop_transport_init(&platform,python,config)) return 2;
    char default_preferences[1024];
    if(!preferences_path) {
        char *directory=SDL_GetPrefPath("NDX2","Controller");
        if(directory) { snprintf(default_preferences,sizeof(default_preferences),"%spreferences.bin",directory); SDL_free(directory); preferences_path=default_preferences; }
    }
    if(preferences_path) desktop_preferences_init(&platform,preferences_path);
    controller_ui_init(&platform);
    bool running=true; uint64_t last=now_ms(),started=last,next=last+2500; unsigned stage=0; int exit_code=0;
    while(running) {
        SDL_Event e; while(SDL_PollEvent(&e)) {
            if(e.type==SDL_QUIT) running=false;
            if(e.type==SDL_MOUSEBUTTONDOWN||e.type==SDL_MOUSEBUTTONUP) { down=e.type==SDL_MOUSEBUTTONDOWN; px=e.button.x; py=e.button.y; controller_ui_touch(down); }
            if(e.type==SDL_MOUSEMOTION) { px=e.motion.x; py=e.motion.y; }
        }
        uint64_t now=now_ms(); lv_tick_inc((uint32_t)(now-last)); last=now; lv_timer_handler(); SDL_Delay(5);
        if(release_at&&now>=release_at) { down=false; release_at=0; }
        if(smoke&&now>=next) {
            const controller_t *s=controller_ui_state();
            next=now+500;
            if(transport_smoke) {
                if(controller_ui_ready()) {
                    if(stage==0&&!strcmp(s->transport,"playing")) { capture(smoke,"playing"); tap(464,350); stage++; }
                    else if(stage==1&&!strcmp(s->transport,"paused")) { capture(smoke,"paused"); tap(464,350); stage++; }
                    else if(stage==2&&!strcmp(s->transport,"playing")) { capture(smoke,"resumed"); tap(552,350); stage++; }
                    else if(stage==3&&!strcmp(s->current.reference,"inputs/tidal/tracks/102")&&s->position_ms==0) { capture(smoke,"next"); tap(376,350); stage++; }
                    else if(stage==4&&!strcmp(s->current.reference,"inputs/tidal/tracks/101")) { capture(smoke,"previous"); tap(376,350); stage++; }
                    else if(stage==5&&!strcmp(s->current.reference,"inputs/tidal/tracks/103")) { capture(smoke,"previous-wrap"); tap(552,350); stage++; }
                    else if(stage==6&&!strcmp(s->current.reference,"inputs/tidal/tracks/101")) { capture(smoke,"next-wrap"); puts("PASS native Play/Pause icons and Next/Previous track sequence"); running=false; }
                }
                if(SDL_GetTicks64()-started>20000) { fprintf(stderr,"Transport smoke timed out at stage %u\n",stage); exit_code=10; running=false; }
                continue;
            }
            if(preferences_smoke) {
                switch(stage) {
                case 0:
                    if(!strcmp(preferences_smoke,"check")&&(s->palette!=1||s->brightness!=65||s->timeout!=5)) { exit_code=7; running=false; break; }
                    tap(756,30); stage++; break;
                case 1: if(s->context.screen==SETTINGS) { tap(330,120); stage++; } break;
                case 2: if(s->context.screen==DISPLAY) {
                    if(!strcmp(preferences_smoke,"save")) { tap(400,210); stage++; }
                    else { capture(smoke,"15-preferences-restored"); puts("PASS preferences restored in fresh native process"); running=false; }
                } break;
                case 3: if(s->palette==1) {
                    /* Native value-change events from the actual Display widgets. */
                    lv_obj_t *slider=find_widget(lv_scr_act(),&lv_slider_class), *dropdown=find_widget(lv_scr_act(),&lv_dropdown_class);
                    if(!slider||!dropdown) { exit_code=8; running=false; break; }
                    lv_slider_set_value(slider,65,LV_ANIM_OFF); lv_event_send(slider,LV_EVENT_VALUE_CHANGED,NULL);
                    lv_dropdown_set_selected(dropdown,2); lv_event_send(dropdown,LV_EVENT_VALUE_CHANGED,NULL);
                    next=now+1200; stage++;
                } break;
                case 4:
                    if(s->brightness!=65||s->timeout!=5||!controller_ui_save_preferences()) { exit_code=8; running=false; break; }
                    capture(smoke,"14-preferences-saved"); puts("PASS preferences edited and saved through native UI"); running=false; break;
                }
                if(SDL_GetTicks64()-started>15000) { exit_code=9; running=false; }
                continue;
            }
            switch(stage) {
            case 0: if(controller_ui_ready()) { capture(smoke,"01-now"); tap(290,440); stage++; } break;
            case 1: if(s->context.screen==FIND&&controller_ui_ready()) { tap(664,108); stage++; } break;
            case 2: if(s->context.count&&controller_ui_ready()) { capture(smoke,"02-find"); tap(330,236); stage++; } break;
            case 3: if(s->context.screen==DETAILS&&controller_ui_ready()) { capture(smoke,"03-details"); tap(60,30); stage++; } break;
            case 4: if(s->context.screen==FIND&&controller_ui_ready()) { if(s->context.count!=12) { exit_code=3; running=false; } tap(330,236); stage++; } break;
            case 5: if(s->context.screen==DETAILS&&controller_ui_ready()&&s->context.playable) { tap(310,356); stage++; } break;
            case 6: if(s->context.screen==NOW&&strstr(s->title,"A Still Morning")&&controller_ui_ready()) { capture(smoke,"04-playing"); tap(290,440); stage++; } break;
            case 7: if(s->context.screen==FIND&&controller_ui_ready()) { tap(744,108); stage++; } break;
            case 8: if(s->context.screen==VOICE&&s->voice==VOICE_RECORDING) { capture(smoke,"05-recording"); tap(390,292); stage++; } break;
            case 9: if(s->voice==VOICE_RECORDING) { tap(160,292); stage++; } break;
            case 10: if(s->context.screen==FIND&&s->context.count&&strstr(s->context.query,"quiet")&&controller_ui_ready()) { capture(smoke,"06-voice-search"); tap(744,108); stage++; } break;
            case 11: if(s->voice==VOICE_RECORDING) { tap(620,292); stage++; } break;
            case 12: if(s->context.screen==FIND&&s->voice==VOICE_IDLE) { tap(756,30); stage++; } break;
            case 13: if(s->context.screen==SETTINGS) { capture(smoke,"07-settings"); tap(330,120); stage++; } break;
            case 14: if(s->context.screen==DISPLAY) { capture(smoke,"08-display"); tap(60,30); stage++; } break;
            case 15: if(s->context.screen==SETTINGS) { tap(100,440); stage++; } break;
            case 16: if(s->context.screen==NOW&&controller_ui_ready()) { tap(440,200); stage++; } break;
            case 17: if(s->context.screen==DETAILS&&controller_ui_ready()&&!strcmp(s->context.selected.kind,"artists")) {
                capture(smoke,"09-artist"); tap(640,140); stage++;
            } break;
            case 18: if(s->context.saved==SAVED_YES&&controller_ui_ready()) { capture(smoke,"10-following"); tap(60,30); stage++; } break;
            case 19: if(s->context.screen==NOW&&controller_ui_ready()) { tap(410,138); stage++; } break;
            case 20: if(s->context.screen==DETAILS&&controller_ui_ready()) {
                if(strcmp(s->context.selected.kind,"tracks")||s->context.saved!=SAVED_NO) { exit_code=5; running=false; break; }
                capture(smoke,"11-track"); tap(540,356); stage++;
            } break;
            case 21: if(s->context.saved==SAVED_YES&&controller_ui_ready()) { tap(290,440); stage++; } break;
            case 22: if(s->context.screen==FIND&&controller_ui_ready()) { tap(744,108); stage++; } break;
            case 23: if(s->voice==VOICE_RECORDING) { smoke_clock_offset+=30000; next=now_ms()+500; stage++; } break;
            case 24: if(s->voice==VOICE_STOPPED&&s->context.screen==VOICE) { capture(smoke,"12-voice-limit"); tap(620,292); stage++; } break;
            case 25: if(s->context.screen==FIND&&s->voice==VOICE_IDLE) {
                controller_ui_disconnect(); tap(100,440); stage++; break;
            } break;
            case 26: if(controller_ui_ready()) {
                if(s->context.screen!=FIND) { exit_code=6; running=false; break; }
                capture(smoke,"13-wake-restored"); puts("PASS native UI: details/Back/play/voice limit/restart/search/cancel/follow/library/settings/wake contact"); running=false;
            } break;
            }
            if(SDL_GetTicks64()-started>30000) { fprintf(stderr,"Native UI smoke timed out at stage %u\n",stage); exit_code=4; running=false; }
        }
    }
    controller_ui_save_preferences(); desktop_preferences_close();
    desktop_transport_close(); SDL_DestroyTexture(texture); SDL_DestroyRenderer(renderer); SDL_DestroyWindow(window); SDL_Quit(); return exit_code;
}

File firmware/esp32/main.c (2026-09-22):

/* Vendor RGB/touch driver stays in the generated, checksum-pinned project. */
#include "waveshare_rgb_lcd_port.h"
#include "esp_timer.h"
#include "esp_system.h"
#include "ui.h"
#include "fixture.h"
#include "preferences_nvs.h"
#include "bridge_transport.h"
static uint64_t now_ms(void) { return esp_timer_get_time()/1000; }
static void diagnostic(const char *event) {
    ESP_LOGI("HP01", "ms=%llu event=%s free_heap=%lu min_heap=%lu fixture=1",
        (unsigned long long)now_ms(),event,(unsigned long)esp_get_free_heap_size(),
        (unsigned long)esp_get_minimum_free_heap_size());
}
void app_main(void) {
    diagnostic("boot_no_sleep_no_microphone");
    ESP_ERROR_CHECK(waveshare_esp32_s3_rgb_lcd_init());
    static platform_t platform;
    platform=fixture_platform(now_ms,diagnostic);
    diagnostic(esp_bridge_start(&platform)?"protected_bridge_client":"silent_fixture_no_provisioning");
    esp_preferences_init(&platform);
    if (lvgl_port_lock(-1)) {
        controller_ui_init(&platform);
        lvgl_port_unlock();
    }
}

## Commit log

2026-09-20 Add metadata-only TIDAL catalogue search prototype
2026-09-20 Add hardware design, parts BOM and power selection plan
2026-09-20 Refine base battery power route and component shortlist
2026-09-20 Add landscape controller UI and native-only prototype bridge
2026-09-20 Define stationary River Stone enclosure and checked packaging layout
2026-09-21 Develop River Stone shell study and validate display insertion
    [assembly-envelopes.step, cover-study.step, cover-study.stl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]
2026-09-21 Add River Stone retainer study and document print audit
    [assembly-envelopes.step, cover-study.step, cover-study.stl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]
2026-09-21 Reinforce River Stone shell and add validated screen-edge bevel
    [assembly-envelopes.step, cover-study.step, cover-study.stl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]
2026-09-21 Add P1S fit-trial project and measured shell slicing comparison
    [fit-coupons.3mf, fit-coupons.stl, machine.json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]
2026-09-21 Document UK prototype procurement BOM and microphone integration candidates
2026-09-22 Research larger battery packs and recommend BAT0014 for prototype
2026-09-22 Record USB-C power supply as already owned; remove PSU purchase cost
2026-09-22 Record six Pi Hut prototype parts as ordered
2026-09-22 Record Pimoroni 10050mAh battery as ordered and correct checkout cost
2026-09-22 Consolidate hardware BOM order status and outstanding assembly work
2026-09-22 Fix silent fixture Play Pause feedback and record visual polish gap
    [main.c]
2026-09-22 Show silent fixture track changes for Next and Previous
    [main.c]
2026-09-23 Register desktop contact before background read timers
2026-09-23 Stabilize native smoke input and completed-frame presentation
    [main.c]
2026-09-23 Close out prototype chat and pause for revised design direction
2026-09-23 Add Still Water bridge previews and battery charge reporting
    Adopt the preserved Still Water design package under D029 with screen selection open. Extend authenticated artwork with bounded 320px chunks, store only the last battery report, and return window/sta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
2026-09-25 Park Waveshare fallback and propose concealed iPhone 11 mounting
2026-09-25 Develop River Stone iPhone mounting layout and aperture trial
2026-09-26 Enlarge iPhone aperture to 6.5 mm perimeter overlap
2026-09-26 Reduce iPhone aperture overlap to 6 mm
2026-09-27 Add open iPhone aperture fit sample and verified print meshes
    [aperture-frame.step, aperture-frame.stl, spacer-0.4mm.step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]
2026-09-28 Add end locating tabs to iPhone fit sample v2
    [aperture-frame.step, aperture-frame.stl, spacer-0.4mm.step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]
2026-10-10 Record measured Lightning plug and parameterize cable clearance
2026-10-24 Adopt cable allowance and front USB routing assumptions
2026-10-24 Document corrected phone fit sample print and trial procedure
